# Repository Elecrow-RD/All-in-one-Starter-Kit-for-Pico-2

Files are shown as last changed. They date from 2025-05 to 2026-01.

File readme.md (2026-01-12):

### 1, Product picture

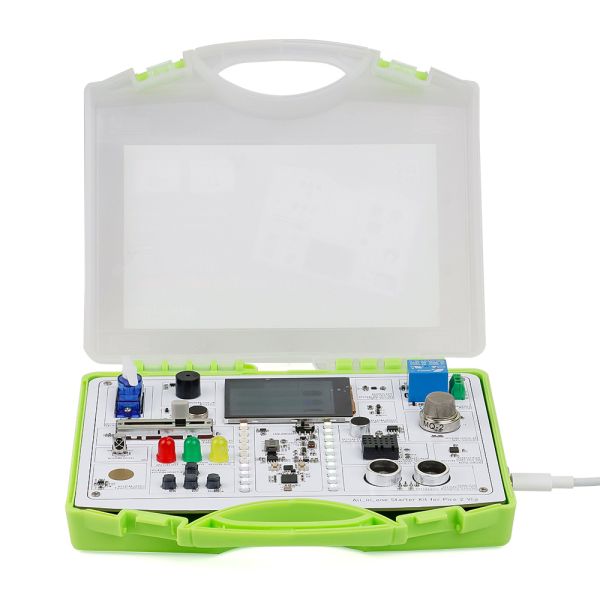
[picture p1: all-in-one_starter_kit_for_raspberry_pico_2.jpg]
all-in-one_starter_kit_for_raspberry_pico_2


https://www.elecrow.com/all-in-one-starter-kit-for-pico-2-with-common-board-design-17-sensors-and-21-lessons.html

### 2, Product version number

| | Hardware | Software | Remark |
| ---- | --- | --- | --- |
| 1 | V1.0 | V1.0 | old |
| 1 | V1.1 | V1.1 | old |
| 1 | V1.2 | V1.1 | old |
| 1 | V1.3 | V1.1 | latest |

#### v1.1 Update:

Replaced gyroscope sensor chip, removed MPU6050 circuit, and replaced it with LSM6DS3 circuit. Rearranged positions of red, green, and yellow LED beads.

#### v1.3 Update:
Added a switching power supply for the servo.

### 3, product information

- Main Processor IC: RP2350A
- Interface: Type-C Interface
- Size: 195*170*46(mm)
- Material:PP(Non-toxic)
- Weight: 340g

| | [ All-in-one Starter Kit for Pico 2](https://www.elecrow.com/all-in-one-starter-kit-for-pico-2-with-common-board-design-17-sensors-and-21-lessons.html) |
| --- | --- |
| Main Processor | Pico 2 RP2350 |
| Number of Sensors | 17 sensors |
| Sensor Board Design | Integrated sensor board, no soldering or complex wiring required |
| Screen | 2.4-inch TFT full-color touch screen |
| Ambient Lights | 20 full-color ambient lights, switchable via touch screen |
| Built-in Mini Games | Yes |
| Expansion Interfaces | None |
| Programming Environment | Based on Arduino software |
| Number of Tutorials | 21 creative tutorials |
| Dimension | 195×170×46 mm |
| Target Audience | Students, teachers, hardware enthusiasts |
| Application Scenarios | Ideal for learning Pico 2 programming basics |

### 4,Quick Start

##### Arduino IDE starts

1.Download the library files used by this product to the 'libraries' folder.

C:\Users\Documents\Arduino\libraries\



2.Open the Arduino IDE

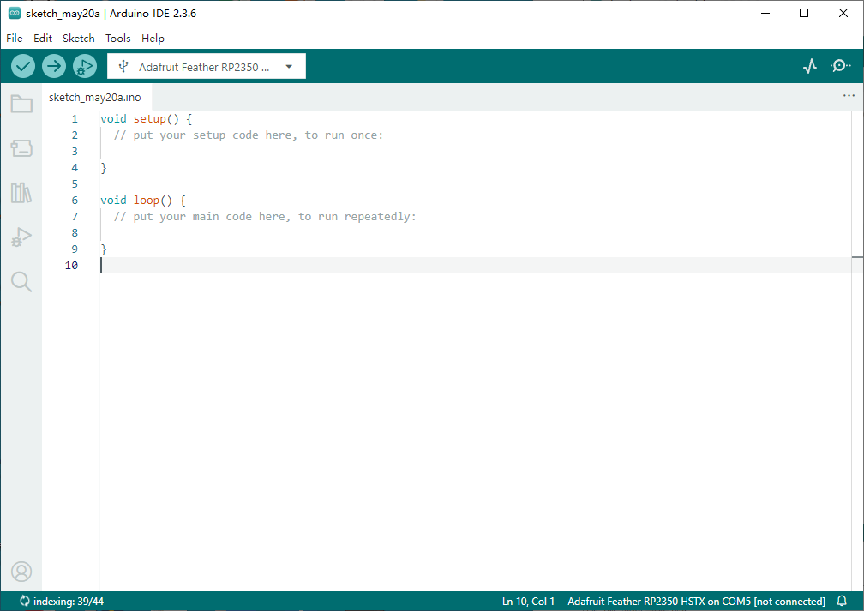
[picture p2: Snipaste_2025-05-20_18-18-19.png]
Snipaste_2025-05-20_18-18-19


3.Open the code configuration environment and burn it

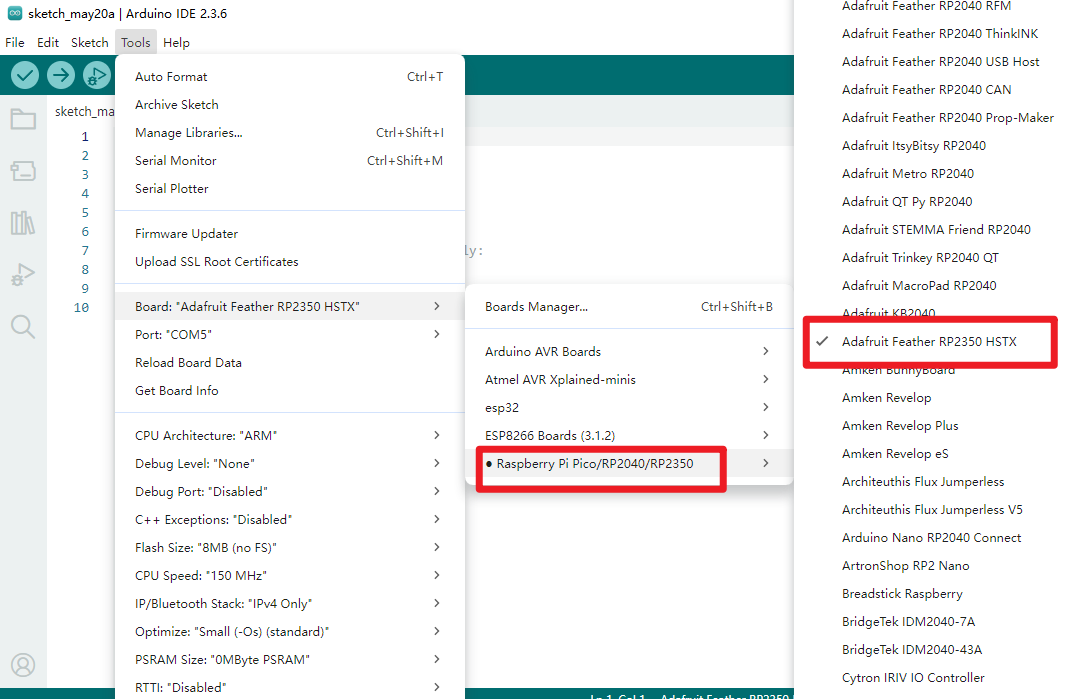
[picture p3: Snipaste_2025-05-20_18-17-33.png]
Snipaste_2025-05-20_18-17-33


### 5,Folder structure.

|--3D file： Contains 3D model files (.stp) for the hardware. These files can be used for visualization, enclosure design, or integration into CAD software.

|--Datasheet: Includes datasheets for components used in the project, providing detailed specifications, electrical characteristics, and pin configurations.

|--Eagle_SCH&PCB: Contains **Eagle CAD** schematic (`.sch`) and PCB layout (`.brd`) files. These are used for circuit design and PCB manufacturing.

|--example: Provides example code and projects to demonstrate how to use the hardware and libraries. These examples help users get started quickly.

|--factory_firmware: Stores pre-compiled factory firmware that can be directly flashed onto the device. This ensures the device runs the default functionality.

|--factory_sourcecode: Contains the source code for the factory firmware, allowing users to modify and rebuild the firmware as needed.

### 6,Pin definition

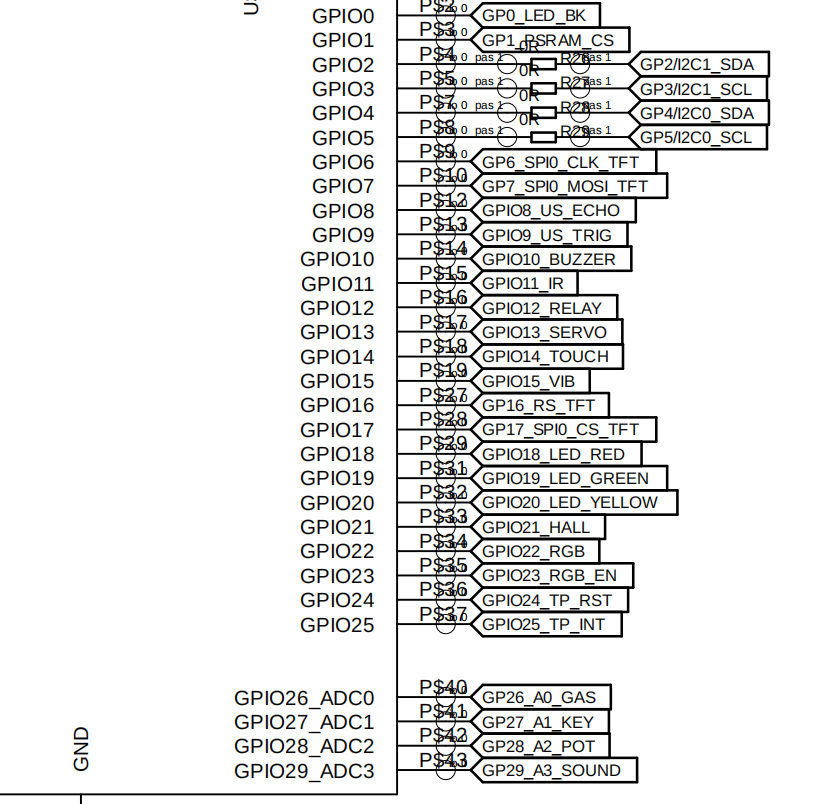
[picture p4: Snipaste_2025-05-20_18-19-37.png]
Snipaste_2025-05-20_18-19-37


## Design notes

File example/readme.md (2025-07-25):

**pico_Arduino_code**: This folder contains sample programs for the Arduino platform, known for its ease of use and versatility in creating interactive electronic projects.

For course code guidance, please refer to this manual：

[All-in-one_Starter_Kit_for_Pico_2_User_Manual](https://www.elecrow.com/download/product/SEP0005K/All-in-one_Starter_Kit_for_Pico_2_User_Manual.pdf)

**pico_micropython_code**: This folder contains sample programs and firmware for the micropython platform.

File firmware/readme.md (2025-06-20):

## Factory Firmware Download Guide

#### 1.Use type-c cable to connect the pico device, long press the boot button, then short press the reset button once, and finally release the boot button, you can see a new disc drive in my computer.



#### 2.Drag and drop the factory firmware xxx.uf2 file to the new disc drive and copy it to finish.





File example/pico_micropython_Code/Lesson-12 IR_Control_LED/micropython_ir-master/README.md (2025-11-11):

# Device drivers for IR (infra red) remote controls

This repo provides a driver to receive from IR (infra red) remote controls and
a driver for IR "blaster" apps. The device drivers are nonblocking. They do not
require `uasyncio` but are compatible with it, and are designed for standard
firmware builds.

The receiver is cross platform and has been tested on Pyboard, ESP8266, ESP32
and Raspberry Pi Pico.

In a typical use case the receiver is employed at the REPL to sniff the address
and data values associated with buttons on a remote control. The transmitter is
then used in an application to send those codes, emulating the remote control.

Other use cases involve running the receiver in an application. This enables an
IR remote to control a device such as a robot. This may be problematic on some
platforms. Please see [section 4](./README.md#4-receiver-limitations).

## Raspberry Pi Pico note

Early firmware has [this issue](https://github.com/micropython/micropython/issues/6866)
affecting USB communication with some PC's. This is now fixed. Please ensure
you are using up to date firmware.

#### [Receiver docs](./RECEIVER.md)

The transmitter driver is compatible with Pyboard (1.x and D series) and ESP32.
ESP8266 is unsupported; it seems incapable of generating the required signals.

#### [Transmitter docs](./TRANSMITTER.md)

# 1. IR communication

IR communication uses a carrier frequency to pulse the IR source. Modulation
takes the form of OOK (on-off keying). There are multiple protocols and at
least three options for carrier frequency: 36, 38 and 40KHz.

In the case of the transmitter the carrier frequency is a runtime parameter:
any value may be specified. The receiver uses a hardware demodulator which
should be purchased for the correct frequency. The receiver device driver sees
the demodulated signal and is hence carrier frequency agnostic.

Remotes transmit an address and a data byte, plus in some cases an extra value.
The address denotes the physical device being controlled. The data defines the
button on the remote. Provision usually exists for differentiating between a
button repeatedly pressed and one which is held down; the mechanism is protocol
dependent.

# 2. Supported protocols

The drivers support NEC and Sony protocols plus two Philips protocols, namely
RC-5 and RC-6 mode 0. There is also support for the OrtekMCE protocol used on
VRC-1100 remotes. These originally supported Microsoft Media Center but can be
used to control Kodi and (with a suitable receiver) to emulate a PC keyboard.
The Samsung protocol (NEC variant) is also supported.

Examining waveforms from various remote controls it is evident that numerous
protocols exist. Some are doubtless proprietary and undocumented. The supported
protocols are those for which I managed to locate documentation. My preference
is for the NEC version. It has conservative timing and good provision for error
detection. RC-5 has limited error detection, and RC-6 mode 0 has rather fast
timing.

A remote using the NEC protocol is [this one](https://www.adafruit.com/products/389).

# 3. Hardware Requirements

These are discussed in detail in the relevant docs; the following provides an
overview.

The receiver is cross-platform. It requires an IR receiver chip to demodulate
the carrier. The chip must be selected for the frequency in use by the remote.
For 38KHz devices a receiver chip such as the Vishay TSOP4838 or the
[adafruit one](https://www.adafruit.com/products/157) is required. This
demodulates the 38KHz IR pulses and passes the demodulated pulse train to the
microcontroller.

In my testing a 38KHz demodulator worked with 36KHz and 40KHz remotes, but this
is obviously neither guaranteed nor optimal.

The transmitter requires a Pyboard 1.x (not Lite), a Pyboard D, an ESP32 or
Raspberry Pico (RP2). Output is via an IR LED which will need a transistor to
provide sufficient current.

## 3.1 Carrier frequencies

These are as follows. The Panasonic remote appears to use a proprietary
protocol and is not supported by these drivers.

| Protocol  | F KHz | How found | Support |
|:---:|:-----:|:---:|:---:|
| NEC | 38 | Measured | Y |
| RC-5 RC-6 | 36 | Spec/measured | Y |
| Sony | 40 | Spec/measured | Y |
| MCE | 38 | Measured | Y | 
| Samsung | 38 | Measured | Y |
| Panasonic | 36.3  | Measured | N |

# 4. Receiver limitations

The receiver uses a pin interrupt and depends on a quick response to a state
change on the pin. This is guaranteed on platforms which support hard IRQ's
such as the Pyboard and the RP4 Pico. The ESP32 and ESP8266 only support soft
IRQ's. This means that, if code such as WiFi communication is running
concurrently, reliable reception may be problematic.

# 5. References

Sources of information about IR protocols. The `sbprojects.net` site is an
excellent resource.  
[General information about IR](https://www.sbprojects.net/knowledge/ir/)

Also [IRMP](https://www.mikrocontroller.net/articles/IRMP_-_english)

The NEC protocol:  
[altium](http://techdocs.altium.com/display/FPGA/NEC+Infrared+Transmission+Protocol)  
[circuitvalley](http://www.circuitvalley.com/2013/09/nec-protocol-ir-infrared-remote-control.html)  
[sbprojects.net](https://www.sbprojects.net/knowledge/ir/nec.php)

The Samsung protocol:  
[Rustic Engineering](https://rusticengineering.wordpress.com/2011/02/09/infrared-room-control-with-samsung-ir-protocol/)  
[TechDesign Electronics](https://www.techdesign.be/projects/011/011_waves.htm) Waveforms of various protocols.  

Philips protocols:  
[RC5 Wikipedia](https://en.wikipedia.org/wiki/RC-5)  
[RC5 sbprojects.net](https://www.sbprojects.net/knowledge/ir/rc5.php)  
[RC6 sbprojects.net](https://www.sbprojects.net/knowledge/ir/rc6.php)

Sony protocol:  
[SIRC sbprojects.net](https://www.sbprojects.net/knowledge/ir/sirc.php)

MCE protocol:  
[OrtekMCE](http://www.hifi-remote.com/johnsfine/DecodeIR.html#OrtekMCE)

IR decoders (C sourcecode):  
[in the Linux kernel](https://github.com/torvalds/linux/tree/master/drivers/media/rc)

Interesting summary of IR protools (with thanks to Martin Bless):  
[IRMP](https://www.mikrocontroller.net/articles/IRMP_-_english#IR_Protocols)

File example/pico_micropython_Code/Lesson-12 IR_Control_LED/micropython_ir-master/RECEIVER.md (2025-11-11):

# IR Receiver

##### [Main README](./README.md#1-ir-communication)

# 1. Hardware Requirements

The receiver is cross-platform. It requires an IR receiver chip to demodulate
the carrier. The chip must be selected for the frequency in use by the remote.
For 38KHz devices a receiver chip such as the Vishay TSOP4838 or the
[adafruit one](https://www.adafruit.com/products/157) is required. This
demodulates the 38KHz IR pulses and passes the demodulated pulse train to the
microcontroller. The tested chip returns a 0 level on carrier detect, but the
driver design ensures operation regardless of sense.

In my testing a 38KHz demodulator worked with 36KHz and 40KHz remotes, but this
is obviously neither guaranteed nor optimal.

The TSOP4838 can run from 3.3V or 5V supplies. The former should be used on
non-5V compliant hosts such as ESP32 and Raspberry Pi Pico and is fine on 5V
compliant hosts too.

The pin used to connect the decoder chip to the target is arbitrary. The test
program `acquire.py` uses the following pins by default:

| Host | Pin | Notes |
|:---:|:---:|:-----:|
| Pyboard | X3  |  |
| ESP32 | 23  |  |
| ESP8266 | 13  |  |
| D1 Mini | D7  | WeMos name for pin 13. |
| Pico | 16  |  |

A remote using the NEC protocol is [this one](https://www.adafruit.com/products/389).

# 2. Installation and demo scripts

The receiver is a Python package. This minimises RAM usage: applications only
import the device driver for the protocol in use. It may be installed using
 [mpremote](https://docs.micropython.org/en/latest/reference/mpremote.html) on
 the PC:
```bash
$ mpremote mip install "github:peterhinch/micropython_ir/ir_rx"
```
There are no dependencies.

## 2.1 Test scripts

The demo can be used to characterise IR remotes where the protocol is known. It
displays the codes returned by each button. This can aid in the design of
receiver applications. The demo prints "running" every 5 seconds and reports
any data received from the remote.
```python
from ir_rx.test import test
```
Instructions will be displayed at the REPL.

If the protocol in use is unknown, there are two options: trial and error with
the above script or run the following:
```python
from ir_rx.acquire import test
test()
```
This script waits for a single burst from the remote and prints the timing of
the pulses followed by its best guess at the protocol. It correctly identifies
supported protocols, but can wrongly identify unsupported protocols. The
report produced by the script exposed to an unknown protocol is unpredictable.
The `test()` function returns a list of the mark and space periods (in μs).

# 3. The driver

This implements a class for each supported protocol. Each class is subclassed
from a common abstract base class in `__init__.py`.

Applications should instantiate the appropriate class with a callback. The
callback will run whenever an IR pulse train is received. Example running on a
Pyboard:
```python
import time
from machine import Pin
from pyb import LED
from ir_rx.nec import NEC_8  # NEC remote, 8 bit addresses

red = LED(1)

def callback(data, addr, ctrl):
    if data < 0:  # NEC protocol sends repeat codes.
        print('Repeat code.')
    else:
        print('Data {:02x} Addr {:04x}'.format(data, addr))

ir = NEC_8(Pin('X3', Pin.IN), callback)
while True:
    time.sleep_ms(500)
    red.toggle()
```

#### Common to all classes

##### Constructor args:  
 1. `pin` is a `machine.Pin` instance configured as an input, connected to the
 IR decoder chip.  
 2. `callback` is the user supplied callback.
 3. `*args` Any further args will be passed to the callback.  

The user callback takes the following args:  
 1. `data` (`int`) Value from the remote. Normally in range 0-255. A value < 0
 signifies an NEC repeat code.
 2. `addr` (`int`) Address from the remote.
 3. `ctrl` (`int`) The meaning of this is protocol dependent:  
 NEC: 0  
 Philips: this is toggled 1/0 on repeat button presses. If the button is held
 down it is not toggled. The  transmitter demo implements this behaviour.  
 Sony: 0 unless receiving a 20-bit stream, in which case it holds the extended
 value.
 4. Any args passed to the constructor.

Bound variable:  
 1. `verbose=False` If `True` emits debug output.

##### Methods:
 1. `error_function` Arg: a function taking a single `int` arg. If specified
 the function will be called if an error occurs. The arg value corresponds to
 the error code. Typical usage might be to provide some user feedback of
 incorrect reception although beware of occasional triggers by external events.
 In my testing the TSOP4838 produces 200µs pulses on occasion for no obvious
 reason. See [section 4](./RECEIVER.md#4-errors).
 2. `close` No args. Shuts down the pin and timer interrupts.

A function is provided to print errors in human readable form. This may be
invoked as follows:

```python
from ir_rx.print_error import print_error  # Optional print of error codes
# Assume ir is an instance of an IR receiver class
ir.error_function(print_error)
```
##### Class variables:
 1. `Timer_id=-1` By default the driver uses a software timer. The ESP32C3  does
 not support these. This class variable offers a workround, See
 [section 5.1](./RECEIVER.md#51-timer-id).
 2. There are constants defining the NEC repeat code and the error codes sent
 to the error function. They are discussed in [section 4](./RECEIVER.md#4-errors).

Users of `uasyncio` please see [Section 8](./RECEIVER.md#8-use-with-uasyncio).

#### NEC classes (includes Samsung)

`NEC_8`, `NEC_16`, `SAMSUNG`

Typical invocation:
```python
from ir_rx.nec import NEC_8
```

Remotes using the NEC protocol can send 8 or 16 bit addresses. If the `NEC_16`
class receives an 8 bit address it will get a 16 bit value comprising the
address in bits 0-7 and its one's complement in bits 8-15.  
The `NEC_8` class enables error checking for remotes that return an 8 bit
address: the complement is checked and the address returned as an 8-bit value.
A 16-bit address will result in an error.

The `SAMSUNG` class returns 16 bit address and data values. The remote sample
tested did not issue repeat codes - if a button is held down it simply repeated
the original value. In common with other NEC classes the callback receives a
value of 0 in the `ctrl` arg.

Thanks are due to J.E.Tannenbaum for information about the Samsung protocol. See
https://github.com/peterhinch/micropython_ir/issues/21#issuecomment-1300421694 and
https://github.com/peterhinch/micropython_ir/issues/44 for some test results.

#### Sony classes

`SONY_12`, `SONY_15`, `SONY_20`

Typical invocation:
```python
from ir_rx.sony import SONY_15
```

The SIRC protocol comes in 3 variants: 12, 15 and 20 bits. `SONY_20` handles
bitstreams from all three types of remote. Choosing a class matching the remote
improves the timing reducing the likelihood of errors when handling repeats: in
20-bit mode SIRC timing when a button is held down is tight. A worst-case 20
bit block takes 39ms nominal, yet the repeat time is 45ms nominal.  
A single physical remote can issue more than one type of bitstream. The Sony
remote tested issued both 12 bit and 15 bit streams.

#### Philips classes

`RC5_IR`, `RC6_M0`

Typical invocation:
```python
from ir_rx.philips import RC5_IR
```

These support the RC-5 (including RC-5X) and RC-6 mode 0 protocols
respectively.

#### Microsoft MCE class

`MCE`

Typical invocation:
```python
from ir_rx.mce import MCE
```

I have been unable to locate a definitive specification: the protocol was
analysed by a mixture of googling and experiment. Behaviour may change if I
acquire new information. The protocol is known as OrtekMCE and the remote
control is sold on eBay as VRC-1100.

The remote was designed for Microsoft Media Center and is used to control Kodi
on boxes such as the Raspberry Pi. With a suitable PC driver it can emulate a
PC keyboard and mouse. The mouse emulation uses a different protocol: the class
does not currently support it. Pressing mouse buttons and pad will cause the
error function (if provided) to be called.

Args passed to the callback comprise 4 bit `addr`, 6 bit `data` and 2 bit `ctrl`
with the latter having the value 0 for the first message and 2 for the message
sent on key release. Intermediate messages (where the key is held down) have
value 1.

There is a 4-bit checksum which is used by default. The algorithm requires an
initial 'seed' value which my testing proved to be 4. However the only
[documentation](http://www.hifi-remote.com/johnsfine/DecodeIR.html#OrtekMCE) I
could find stated that the value should be 3. I implemented this as a class
variable `MCE.init_cs=4`. This enables it to be changed if some remotes use 3.
If the value is set to -1 the check will be skipped.

# 4. Errors

IR reception is inevitably subject to errors, notably if the remote is operated
near the limit of its range, if it is not pointed at the receiver or if its
batteries are low. The user callback is not called when an error occurs.

On ESP8266 and ESP32 there is a further source of errors. This results from the
large and variable interrupt latency of the device which can exceed the pulse
duration. This causes pulses to be missed or their timing measured incorrectly.
On ESP8266 some improvment may be achieved by running the chip at 160MHz.

In general applications should provide user feedback of correct reception.
Users tend to press the key again if the expected action is absent.

In debugging a callback can be specified for reporting errors. The value passed
to the error function are represented by constants indicating the cause of the
error. These are driver ABC class variables and are as follows:

`BADSTART` A short (<= 4ms) start pulse was received. May occur due to IR
interference, e.g. from fluorescent lights. The TSOP4838 is prone to producing
200µs pulses on occasion, especially when using the ESP8266.  
`BADBLOCK` A normal data block: too few edges received. Occurs on the ESP8266
owing to high interrupt latency.  
`BADREP` A repeat block: an incorrect number of edges were received.  
`OVERRUN` A normal data block: too many edges received.  
`BADDATA` Data did not match check byte.  
`BADADDR` (`NEC_IR`) If `extended` is `False` the 8-bit address is checked
against the check byte. This code is returned on failure.  

# 5. Receiver platforms

Currently the ESP8266 suffers from [this issue](https://github.com/micropython/micropython/issues/5714).
Testing was therefore done without WiFi connectivity. If the application uses
the WiFi regularly, or if an external process pings the board repeatedly, the
crash does not occur.

Philips protocols (especially RC-6) have tight timing constraints with short
pulses whose length must be determined with reasonable accuracy. The Sony 20
bit protocol also has a timing issue in that the worst case bit pattern takes
39ms nominal, yet the repeat time is 45ms nominal. These issues can lead to
errors particularly on slower targets. As discussed above, errors are to be
expected. It is up to the user to decide if the error rate is acceptable.

Reception was tested using Pyboard D SF2W, ESP8266 and ESP32 with signals from
remote controls (where available) and from the tranmitter in this repo. Issues
are listed below.

NEC: No issues.  
Sony 12 and 15 bit: No issues.  
Sony 20 bit: On ESP32 some errors occurred when repeats occurred.  
Philips RC-5: On ESP32 with one remote control many errors occurred, but paired
with the transmitter in this repo it worked.  
Philips RC-6: No issues. Only tested against the transmitter in this repo.

## 5.1 Timer ID

The ESP32C3 does not support software timers. This results in a crash. It is
possible to assign a hardware timer as follows (example is for NEC but applies
to any class):
```python
from ir_rx.nec import NEC_8
NEC_8.Timer_id = 0  # Use hardware timer 0
# Code omitted
ir = NEC_8(Pin(8, Pin.IN), callback)
```
Note that assigning a hardware timer is only possible on platforms where the
timer callback is a soft interrupt service routine (see below).

Thanks are due to @Pax-IT for diagnosing this problem.

# 6. Principle of operation

Protocol classes inherit from the abstract base class `IR_RX`. This uses a pin
interrupt to store in an array the time (in μs) of each transition of the pulse
train from the receiver chip. Arrival of the first edge starts a software timer
which runs for the expected duration of an IR block (`tblock`). The use of a
software timer ensures that `.decode` and the user callback can allocate.

When the timer times out its callback (`.decode`) decodes the data. `.decode`
is a method of the protocol specific subclass; on completion it calls the
`do_callback` method of the ABC. This resets the edge reception and calls
either the user callback or the error function (if provided).

The size of the array and the duration of the timer are protocol dependent and
are set by the subclasses. The `.decode` method is provided in the subclass.

CPU times used by `.decode` (not including the user callback) were measured on
a Pyboard D SF2W at stock frequency. They were: NEC 1ms for normal data, 100μs
for a repeat code. Philips codes: RC-5 900μs, RC-6 mode 0 5.5ms.

# 7. Unsupported protocols

It is possible to capture an IR burst from a remote and to re-create it using
the transmitter. This has limitations and is discussed in detail in
[the transmitter doc](./TRANSMITTER.md#5-unsupported-protocols).

# 8. Use with uasyncio

The receiver callback runs in a soft ISR (interrupt service routine) context.
In normal synchronous code this is unlikely to present problems, but the fact
that an interrupt can occur at any time means that care must be taken to avoid
a risk of disrupting `uasyncio` internal data. "Thread safe" techniques should
be used. In particular it is bad practice to create a task in the callback. A
simple approach is to use a [ThreadSafeQueue](https://github.com/peterhinch/micropython-async/blob/master/v3/docs/THREADING.md#22-threadsafequeue):

```python
import uasyncio as asyncio
from threadsafe import ThreadSafeQueue
from machine import Pin
from ir_rx.nec import NEC_16

def callback(data, addr, ctrl, qu):  # Runs in ISR context
    if not qu.full():
        qu.put_sync((data, addr))

async def receiver(q):
    async for data in q:  # Task pauses here until data arrives
        print(f"Received {data}")

async def main():
    q = ThreadSafeQueue([0 for _ in range(20)])
    ir = NEC_16(Pin(16, Pin.IN), callback, q)
    await receiver(q)

asyncio.run(main())
```

The underlying issues are discussed [here](https://github.com/peterhinch/micropython-async/blob/master/v3/docs/INTERRUPTS.md)
and [here](https://github.com/peterhinch/micropython-async/blob/master/v3/docs/THREADING.md).

# Appendix 1 NEC Protocol description

A normal burst comprises exactly 68 edges, the exception being a repeat code
which has 4. An incorrect number of edges is treated as an error. All bursts
begin with a 9ms pulse. In a normal code this is followed by a 4.5ms space; a
repeat code is identified by a 2.25ms space. A data burst lasts for 67.5ms.

Data bits comprise a 562.5µs mark followed by a space whose length determines
the bit value. 562.5µs denotes 0 and 1.6875ms denotes 1.

In 8 bit address mode the complement of the address and data values is sent to
provide error checking. This also ensures that the number of 1's and 0's in a
burst is constant, giving a constant burst length of 67.5ms. In extended
address mode this constancy is lost. The burst length can (by my calculations)
run to 76.5ms.

# Appendix 2 MCE Protocol

The bitstream comprises a header (2ms mark, 1ms space) followed by 16 bits of
Manchester encoded data with a bit time of 500μs. Data are encoded  
```
ccccddddddppaaaa
```
Where `aaaa` is the address, `pp` is the position (toggle) field, `dddddd` is
data and `cccc` is a checksum. This is calculated by counting the ones in
`ddddddppaaaa` and adding 4. Data are transmitted LSB first.

The only [doc](http://www.hifi-remote.com/johnsfine/DecodeIR.html#OrtekMCE) I
could find states that the checksum seed value is 3, but this did not match the
remote I have.

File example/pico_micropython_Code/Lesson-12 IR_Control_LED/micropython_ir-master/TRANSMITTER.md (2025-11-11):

# IR Transmitter

##### [Main README](./README.md#1-ir-communication)

# 1. Hardware Requirements

The transmitter requires a Pyboard 1.x (not Lite), a Pyboard D or an ESP32.
Output is via an IR LED which needs a simple circuit to provide sufficient
current. Typically these need 50-100mA of drive to achieve reasonable range and
data integrity. A suitable 940nm LED is [this one](https://www.adafruit.com/product/387).

On the Pyboard the transmitter test script assumes pin X1 for IR output. It can
be changed, but it must support Timer 2 channel 1. Pins for pushbutton inputs
are arbitrary: X3 and X4 are used. The driver uses timers 2 and 5.

On ESP32 the demo uses pin 23 for IR output and pins 18 and 19 for pushbuttons.
These pins may be changed. The only device resource used is `RMT(0)`.

On Raspberry Pi Pico the demo uses pin 17 for IR output and pins 18 and 19 for
pushbuttons. These pins may be changed. The driver uses the PIO to emulate a
device similar to the ESP32 RMT. The device driver is
[documented here](./RP2_RMT.md); this is for experimenters and those wanting to
use the library in conjunction with their own PIO assembler code.

## 1.1 Wiring

All microcontrollers require an external circuit to drive the LED. The notes
below on specific microcontrollers assume that such a circuit is used.

I use the following circuit which delivers just under 40mA to the diode. R2 may
be reduced for higher current.  
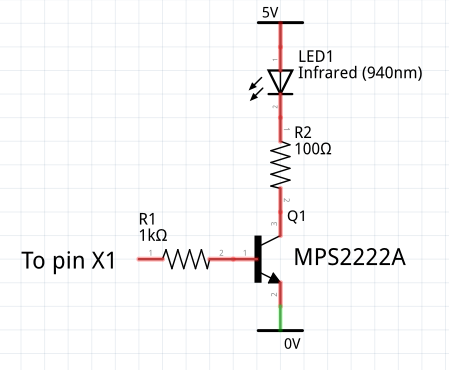
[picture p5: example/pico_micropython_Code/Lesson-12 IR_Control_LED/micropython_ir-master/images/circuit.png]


This alternative delivers a constant current of about 53mA if a higher voltage
than 5V is available. R4 determines the current value and may be reduced to
increase power.  
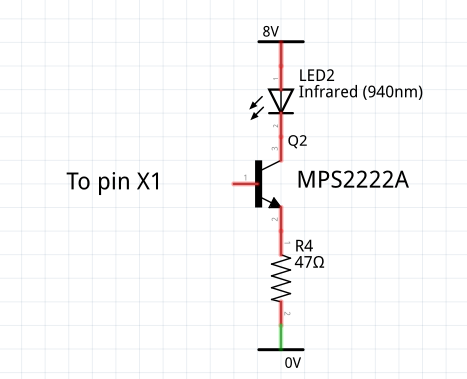
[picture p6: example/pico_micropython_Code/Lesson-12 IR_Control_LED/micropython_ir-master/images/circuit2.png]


The transistor type is not critical.

The driver assumes circuits as shown. Here the carrier "off" state is 0V,
which is the driver default. If using an alternative circuit where "off" is
required to be 3.3V, the class variable `active_high` should be set `False`.

## 1.2 ESP32 Wiring

The ESP32 RMT device now supports the carrier option, and this driver has been
updated to use it. The same circuits as above may be used to connect to pin 23
(or other pin, if the code has been adapted). The `active_high` option is not
available on the ESP32 `RMT` object, so any alternative circuit must illuminate
the LED if the pin state is high.

## 1.3 RP2 Wiring

There is no `active_high` option so the circuit  must illuminate the LED if the
pin state is high, as per the above drivers. Test programs use pin 17, but this
can be reassigned.

# 2. Dependencies and installation

## 2.1 Dependencies

The device driver has no dependencies.

On ESP32 a firmware version >= V1.17 is required.

The demo program uses `uasyncio` primitives from
[this repo](https://github.com/peterhinch/micropython-async). These may be
installed with
```bash
$ mpremote mip install "github:peterhinch/micropython-async/v3/primitives"
```

## 2.2 Installation

The transmitter is a Python package. This minimises RAM usage: applications
only import the device driver for the protocol in use. It may be installed using
 [mpremote](https://docs.micropython.org/en/latest/reference/mpremote.html) on
 the PC:
```bash
$ mpremote mip install "github:peterhinch/micropython_ir/ir_tx"
```
The demo is of a 2-button remote controller with auto-repeat. It may be run by
issuing:
```python
from ir_tx.test import test
```
Instructions will be displayed at the REPL.

# 3. The driver

This is specific to Pyboard D, Pyboard 1.x (not Lite), ESP32 and Raspberry Pi
Pico (RP2 architecture chip).

It implements a class for each supported protocol, namely `NEC`, `SONY_12`,
`SONY_15`, `SONY_20`, `RC5` and `RC6_M0`.  Each class is subclassed from a
common abstract base class in `__init__.py`. The application instantiates the
appropriate class and calls the `transmit` method to send data.

Basic usage on a Pyboard:
```python
from machine import Pin
from ir_tx.nec import NEC
nec = NEC(Pin('X1'))
nec.transmit(1, 2)  # address == 1, data == 2
```
Basic usage on ESP32:
```python
from machine import Pin
from ir_tx.nec import NEC
nec = NEC(Pin(23, Pin.OUT, value = 0))
nec.transmit(1, 2)  # address == 1, data == 2
```
Basic usage on Pico:
```python
from machine import Pin
from ir_tx.nec import NEC
nec = NEC(Pin(17, Pin.OUT, value = 0))
nec.transmit(1, 2)  # address == 1, data == 2
```

#### Common to all classes

Constructor args:  
 1. `pin` A Pin instance instantiated as an output. On a Pyboard this is a
 `pyb.Pin` instance supporting Timer 2 channel 1: `X1` is employed by the test
 script. On ESP32 any `machine.Pin` may be used. Must be connected to the IR
 diode as described below.
 2. `freq=default` The carrier frequency in Hz. The default for NEC is 38000,
 Sony is 40000 and Philips is 36000.
 3. `verbose=False` If `True` emits (a lot of) debug output.

Methods:
 1. `transmit(addr, data, toggle=0, validate=False)` Args `addr`, `data` and
 `toggle` are positive integers. The maximum vaues are protocol dependent. If
 `validate` is `True` passed values are checked and a `ValueError` raised if
 they are out of range. If `validate` is false invalid bits are silently
 discarded. For example if an address of 0x11 is passed to `MCE.transmit`, the
 address sent will be 1 because that protocol supports only a four bit address
 field. The `toggle` field is unused by some protocols when 0 should be passed.
 2. `busy()` Returns `True` while data is being transmitted.

Class method:
 1. `active_low` No args. Pyboard only. A `ValueError` will be thrown on ESP32.
 The IR LED drive circuit is usually designed to turn the LED on if the driver
 pin is high. If it has opposite polarity the method must be called before
 instantiating the class - it will be ineffective if called later.

Class varaible:
 1. `timeit=False` If `True` the `.transmit` method times itself and prints the
 result in μs.

The `transmit` method is synchronous with rapid return. Actual transmission
occurs as a background process, on the Pyboard controlled by timers 2 and 5. On
ESP32 the RMT class is used and on RP2 the PIO is used to emulate the RMT. If
`transmit` is called while a prior transmission is in progress, it will block
until the transmission is complete before commencing the next. Blocking can be
avoided by checking the `busy` status prior to starting a transmission. Note
that sending bursts in quick succession may confuse the receiving device: these
are typically designed for a transmitter that sends a burst in response to a
button press with a gap likely to be well over 100ms.

Execution times were measured on a Pyboard 1.1 and the ESP32 reference board
without SPIRAM. Tests were done at stock frequency and with `validate=True`,
`verbose=False`. A small saving could be achieved by skipping validation.

| Protocol | ESP32 | Pyboard |
|:---:|:-----:|:---:|
| NEC | 7.8ms | 3.2ms |
| SONY12 | 3.2ms | 1.3ms |
| SONY15 | 3.6ms | 1.5ms |
| SONY20 | 4.5ms | 1.9ms |
| RC5 | 4.9ms | 1.5ms |
| RC6_M0 | 6.0ms | 2.0ms |
| MCE | 6.7ms | 2.0ms |

#### NEC class (also Samsung)

Class `NEC`. Example invocation:
```python
from ir_tx.nec import NEC
```

This has an additional method `.repeat` (no args). This causes a repeat code to
be transmitted. Should be called every 108ms if a button is held down.

The NEC protocol accepts 8 or 16 bit addresses. In the former case, a 16 bit
value is transmitted comprising the 8 bit address and its one's complement,
enabling the receiver to perform a simple error check. The `NEC` class supports
these modes by checking the value of `addr` passed to `.transmit` and sending
the complement for values < 256.

A value passed in `toggle` is ignored.

For Samsung protocol set the `samsung` class variable `True`:
```python
from ir_tx.nec import NEC
NEC.samsung=True
```
Samsung remotes do not seem to use repeat codes: the sample I have simply
repeats the original code.

Thanks are due to J.E.Tannenbaum for information about the Samsung protocol. See
https://github.com/peterhinch/micropython_ir/issues/21#issuecomment-1300421694 and
https://github.com/peterhinch/micropython_ir/issues/44 for some test results.

#### Sony classes

Classes `SONY_12`, `SONY_15` and `SONY_20`. Example invocation:
```python
from ir_tx.sony import SONY_15
```

The SIRC protocol supports three sizes, supported by the following classes:
 1. 12 bit (7 data, 5 address) `SONY_12`
 2. 15 bit (7 data, 8 address) `SONY_15`
 3. 20 bit (7 data, 5 addresss, 8 extended) `SONY_20`

The `.transmit` method masks `addr` and `data` values to the widths listed
above. `toggle` is ignored except by `SONY_20` which treats it as the extended
value.

#### Philips classes

Classes `RC5` and `RC6_M0`. Example invocation:
```python
from ir_tx.philips import RC5
```

The RC-5 protocol supports a 5 bit address and 6 or 7 bit (RC5X) data. The
driver uses the appropriate mode depending on the `data` value provided.

The RC-6 protocol accepts 8 bit address and data values.

Both send a `toggle` bit which remains constant if a button is held down, but
changes when the button is released. The application should implement this
behaviour, setting the `toggle` arg of `.transmit` to 0 or 1 as required.

#### Microsoft MCE class

Class `MCE`. Example invocation:
```python
from ir_tx.mce import MCE
# MCE.init_cs = 3
```
There is a separate demo for the `MCE` class because of the need to send a
message on key release. It is run by issuing:
```python
from ir_tx.mcetest import test
```
Instructions will be displayed at the REPL.

I have been unable to locate a definitive specification: the protocol was
analysed by a mixture of googling and experiment. Behaviour may change if I
acquire new information. The protocol is known as OrtekMCE and the remote
control is sold on eBay as VRC-1100.

The remote was designed for Microsoft Media Center and is used to control Kodi
on boxes such as the Raspberry Pi. With a suitable PC driver it can emulate a
PC keyboard and mouse. The mouse emulation uses a different protocol: the class
does not currently support it. Pressing mouse buttons and pad will cause the
error function (if provided) to be called.

This supports a 4 bit address, 6 bit data and 2 bit toggle. The latter should
have a value of 0 for the first message, 1 for repeat messages, and 2 for a
final message sent on button release.

The remaining four bits are a checksum which the driver creates. The algorithm
requires an initial 'seed' value which my testing proved to be 4. However the
only [documentation](http://www.hifi-remote.com/johnsfine/DecodeIR.html#OrtekMCE)
I could find stated that the value should be 3. I implemented this as a class
variable `MCE.init_cs=4`. This enables it to be changed if some receivers
require 3.

# 4. Principle of operation

The classes inherit from the abstract base class `IR`. This has an array `.arr`
to contain the duration (in μs) of each carrier on or off period. The
`transmit` method calls a `tx` method of the subclass which populates this
array. This is done by two methods of the base class, `.append` and `.add`. The
former takes a list of times (in ) and appends them to the array. A bound
variable `.carrier` keeps track of the notional on/off state of the carrier:
this is required for bi-phase (manchester) codings.

The `.add` method takes a single μs time value and adds it to the last value
in the array: this pulse lengthening is used in bi-phase encodings.

On completion of the subclass `.tx`, `.transmit` calls `.trigger` which
initiates transmission as a background process. Its behaviour is platform
dependent.

## 4.1 Pyboard

Tramsmission is performed by two hardware timers initiated in the constructor.
Timer 2, channel 1 is used to configure the output pin as a PWM channel. Its
frequency is set in the constructor. The OOK is performed by dynamically
changing the duty ratio using the timer channel's `pulse_width_percent` method:
this varies the pulse width from 0 to the duty ratio passed to the constructor.

The duty ratio is changed by the Timer 5 callback `._cb`. This retrieves the
next duration from the array. If it is not `STOP` it toggles the duty cycle
and re-initialises T5 for the new duration. If it is `STOP` it ensures that the
duty ratio is set to the `_SPACE`

Here `.trigger` appends a special `STOP` value and initiates physical
transmission by calling the Timer5 callback.

## 4.2 ESP32

The RMT class now supports `carrier_freq` and `carrier_duty_percent`
constructor args, so the base class `IR` (in `__init__.py`) uses these to
enable the OOK (on-off keying) waveform.

The `.trigger` method calls `RMT.write_pulses` and returns with `RMT` operating
in the background.

## 4.3 Duty ratio

In every case where I could find a specified figure it was 30%. I measured
that from a variety of remotes, and in every case it was close to that figure.

# 5. Unsupported protocols

You can use the receiver module to capture an IR burst and replay it with the
transmitter. This enables limited support for unknown protocols. This is
strictly for experimenters and I haven't documented it in detail.

There are two limitations. The first is timing accuracy: both receiving and
transmitting processes introduce some timing uncertainty. This is only likely
to be a practical problem with fast protocols. In brief testing with a known
protocol the scripts below worked.

The more tricky problem is handling repeat keys: different protocols use widely
varying approaches. If repeat keys are to be supported some experimentation and
coding is likely to be required.

The following captures a single burst and saves it to a file:  
```python
from ir_rx.acquire import test
import ujson

lst = test()  # May report unsupported or unknown protocol
with open('burst.py', 'w') as f:
    ujson.dump(lst, f)
```
This replays it:  
```python
from ir_tx import Player
from sys import platform
import ujson

if platform == 'esp32':
    from machine import Pin
    pin = Pin(23, Pin.OUT, value = 0)
else:
    from pyb import Pin, LED
    pin = Pin('X1')
with open('burst.py', 'r') as f:
    lst = ujson.load(f)
ir = Player(pin)
ir.play(lst)
```
The `ir_tx.Player` class is a minimal subclass supporting only the `.play`
method. This takes as an arg an iterable comprising time values of successive
mark and space periods (in μs).

The `ir_rx.acquire.test` function makes assumptions about the likely maximum
length and maximum duration of a burst. In some cases this may require some
modification e.g. to instantiate `IR_GET` with different args.

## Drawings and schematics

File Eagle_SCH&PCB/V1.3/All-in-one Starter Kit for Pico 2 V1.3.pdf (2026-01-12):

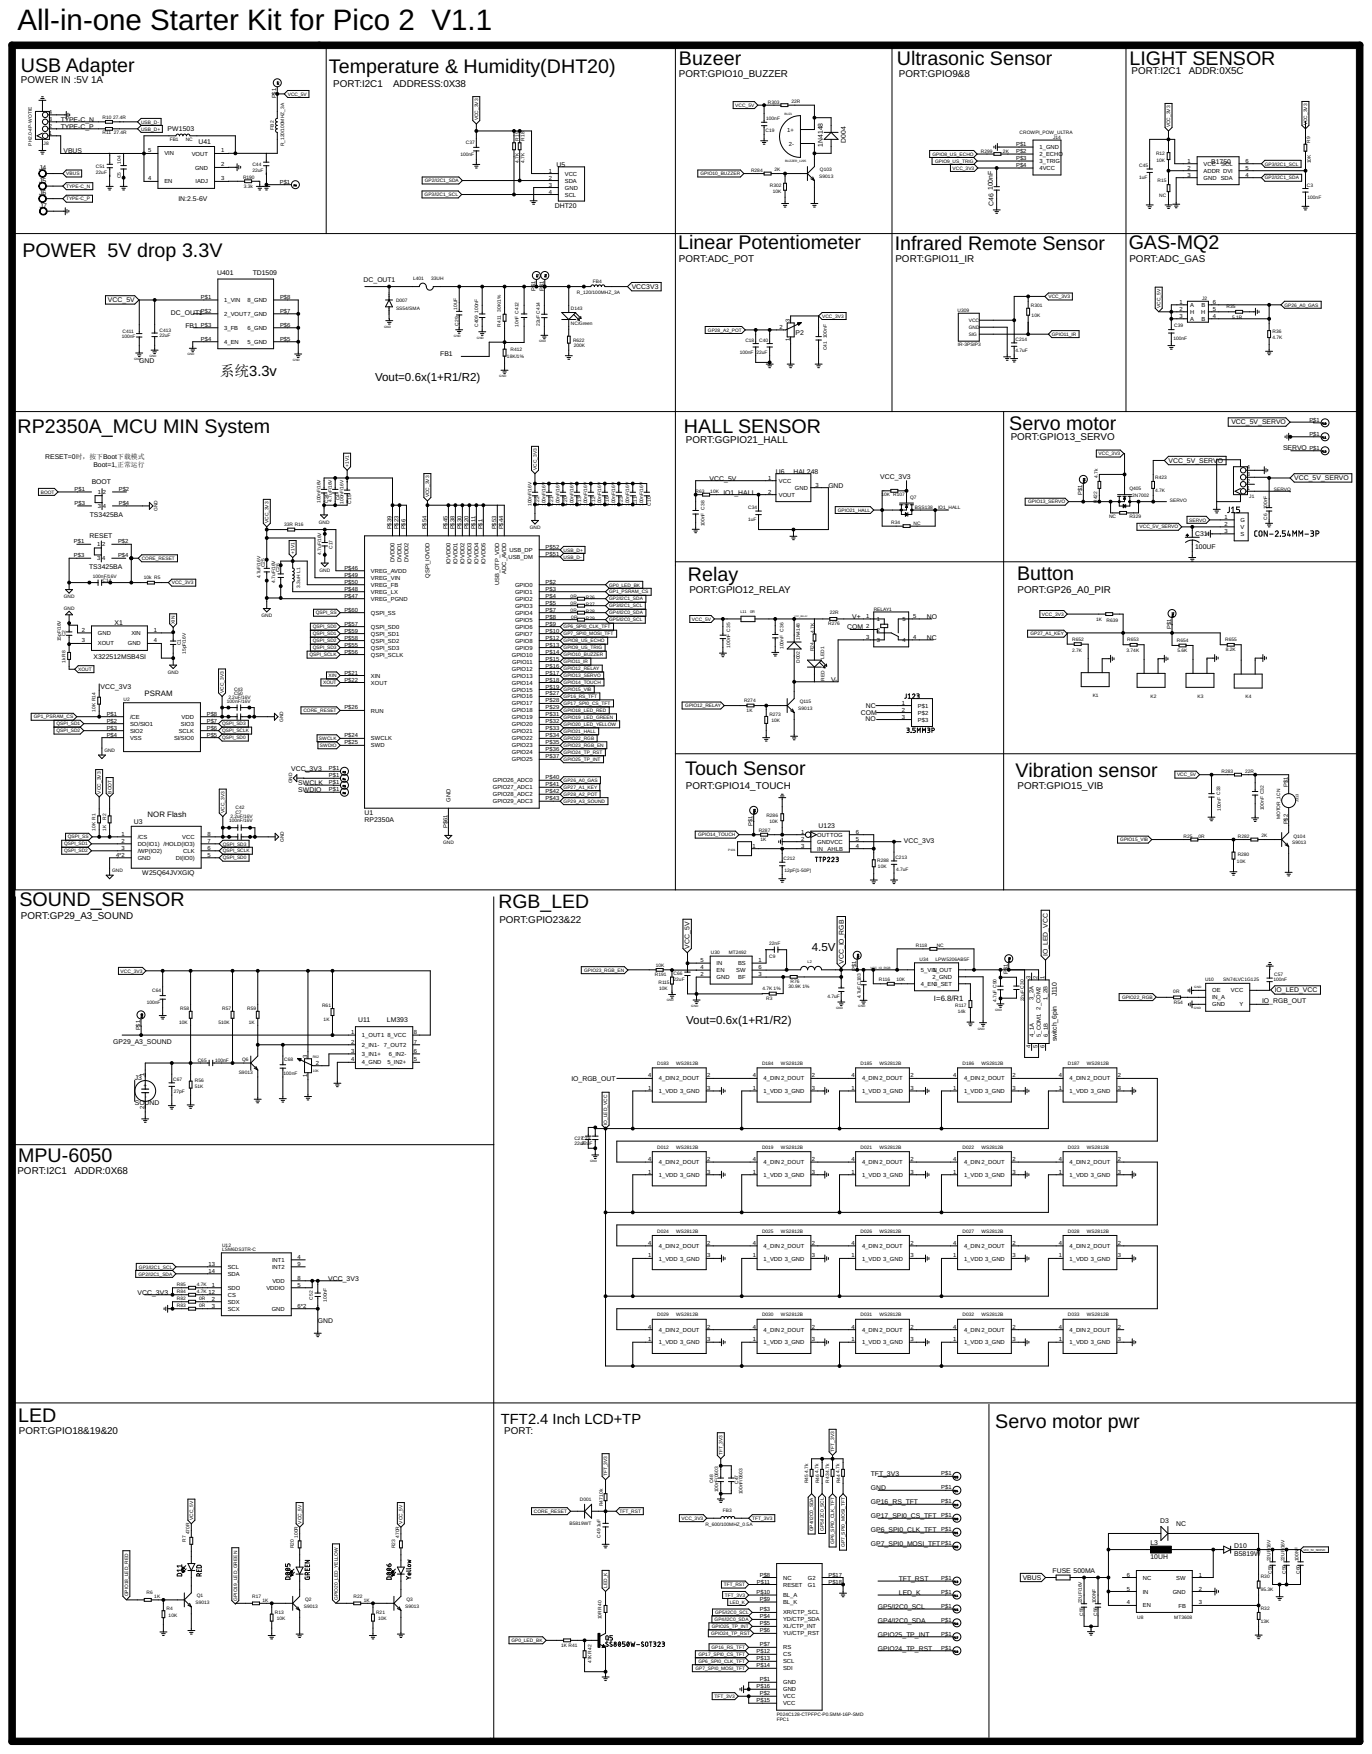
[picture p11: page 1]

All-in-one Starter Kit for Pico 2 V1.1

Infrared Remote Sensor PORT:GPIO11_IR

HALL SENSOR PORT:GGPIO21_HALL HAL248 | Servo motor PORT:GPIO13_SERVO P$1 P$1 P$1 VCC_5V_SERVO

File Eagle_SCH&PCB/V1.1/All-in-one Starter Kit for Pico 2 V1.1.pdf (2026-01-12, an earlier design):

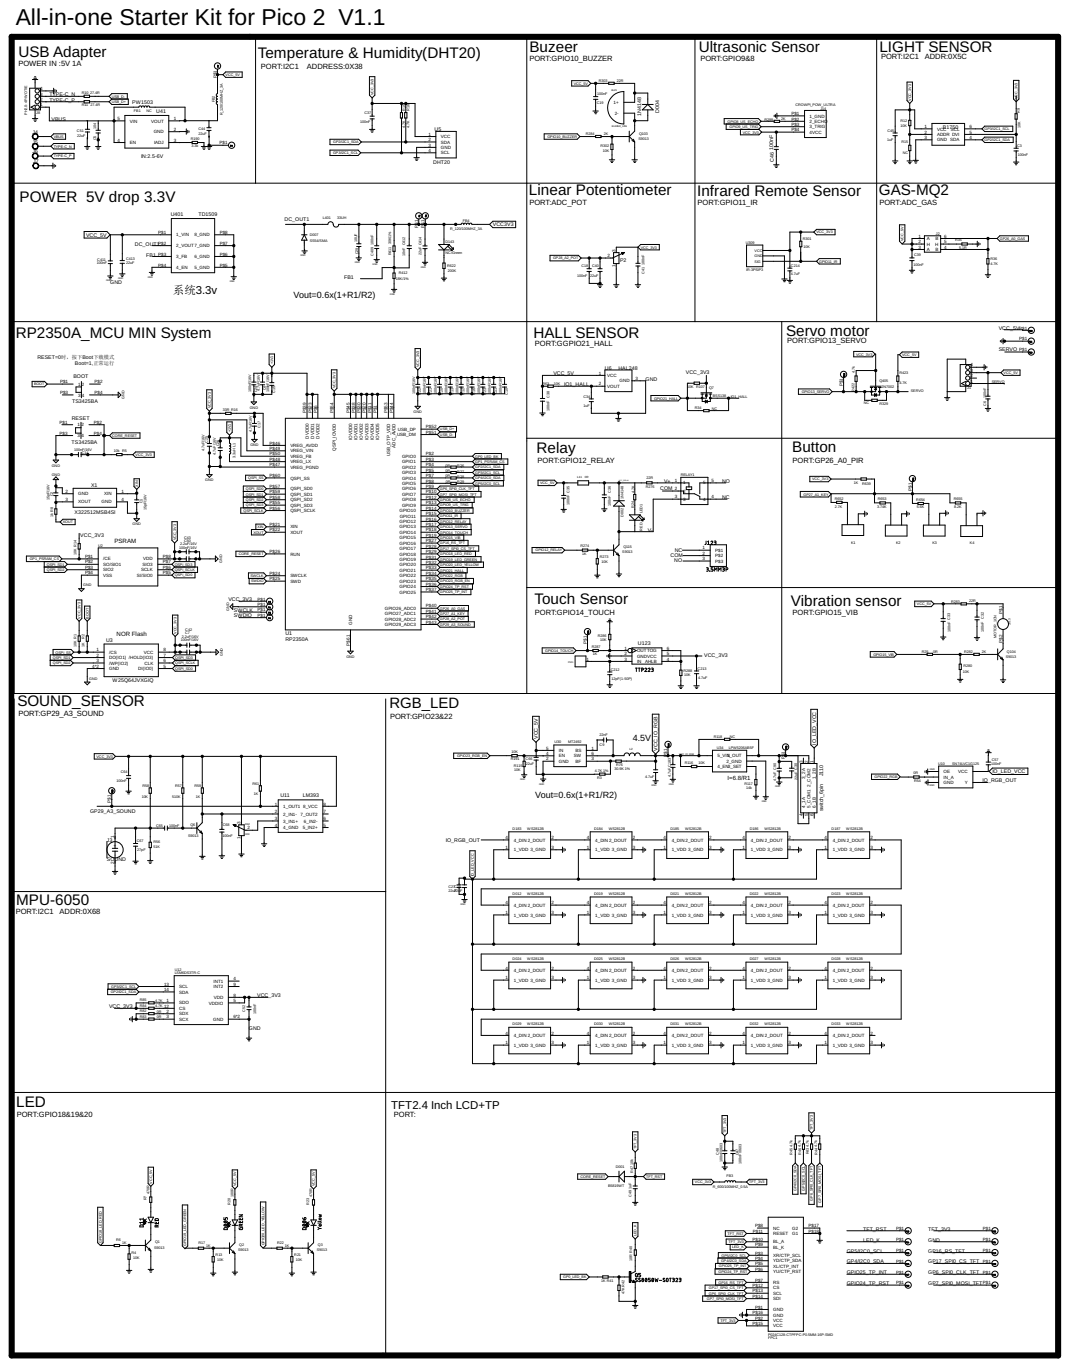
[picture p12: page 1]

All-in-one Starter Kit for Pico 2 V1.1

RP2350A_MCU MIN System | HALL SENSOR PORT:GGPIO21_HALL HAL248 | Servo motor VCC_5V PORT:GPIO13_SERVO

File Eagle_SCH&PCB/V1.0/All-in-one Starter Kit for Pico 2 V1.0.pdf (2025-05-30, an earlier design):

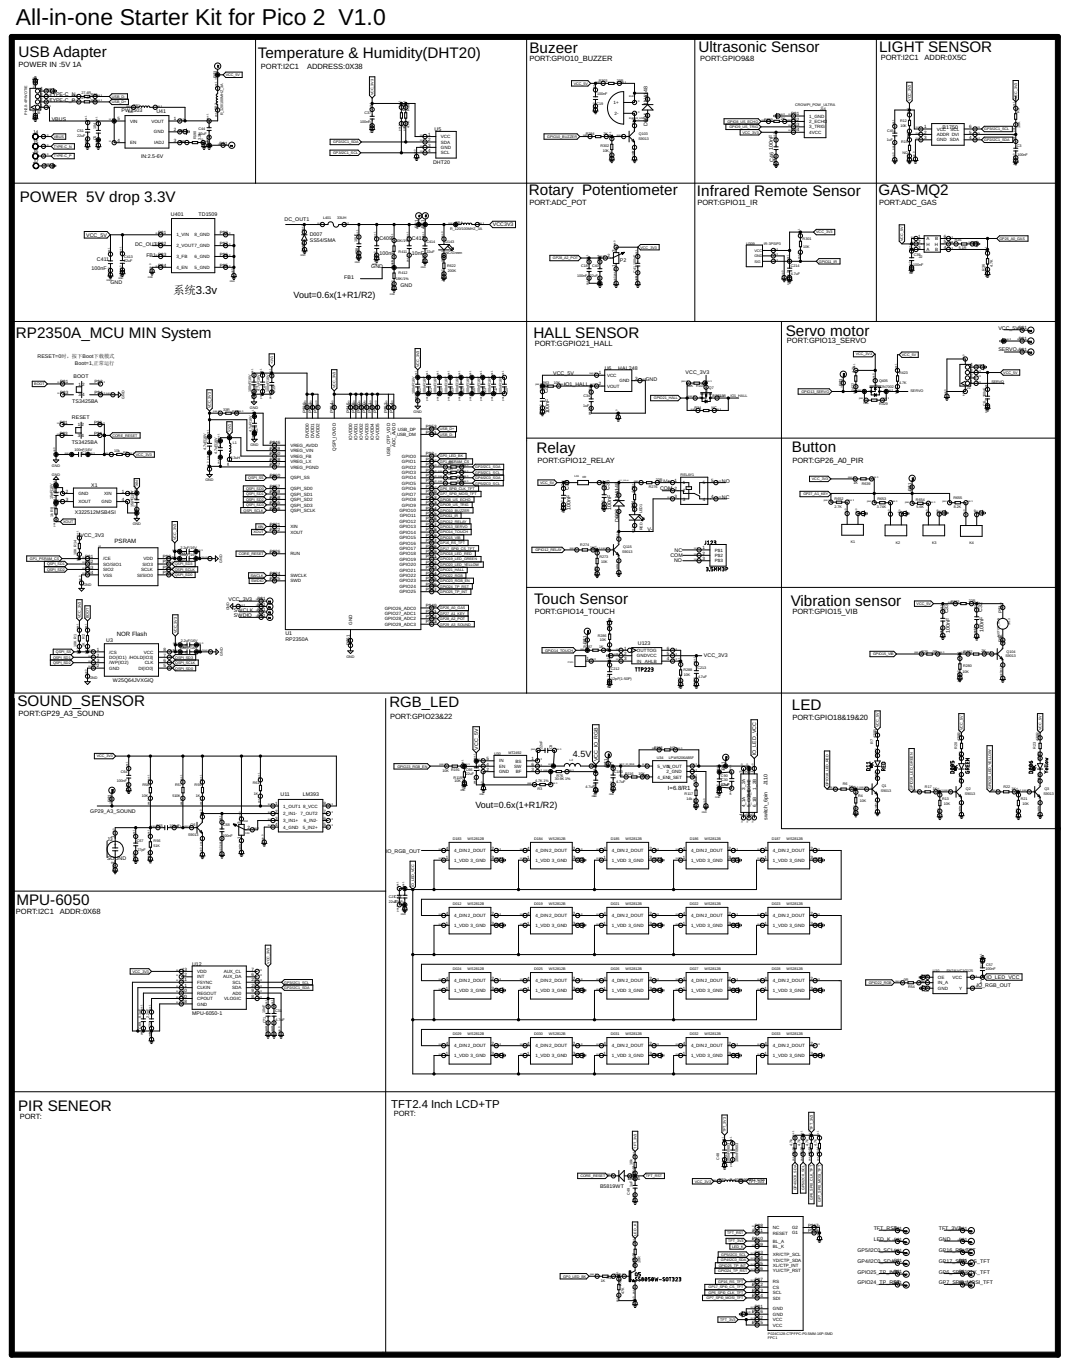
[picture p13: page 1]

All-in-one Starter Kit for Pico 2 V1.0

pas 1 pas 1

sup 0 pas 1 pas 1 pas 1 pas 1

pas 0 pas 0 pas 1 pas 1

pas 1 pas 1 pas 0 pas 0

MPU-6050 PORT:I2C1 ADDR:0X68

PIR SENEOR PORT: | TFT2.4 Inch LCD+TP

pas 3 pas 2 pas 1 pas 1

pas 1 pas 1 sup 0 pas 1 pas 1

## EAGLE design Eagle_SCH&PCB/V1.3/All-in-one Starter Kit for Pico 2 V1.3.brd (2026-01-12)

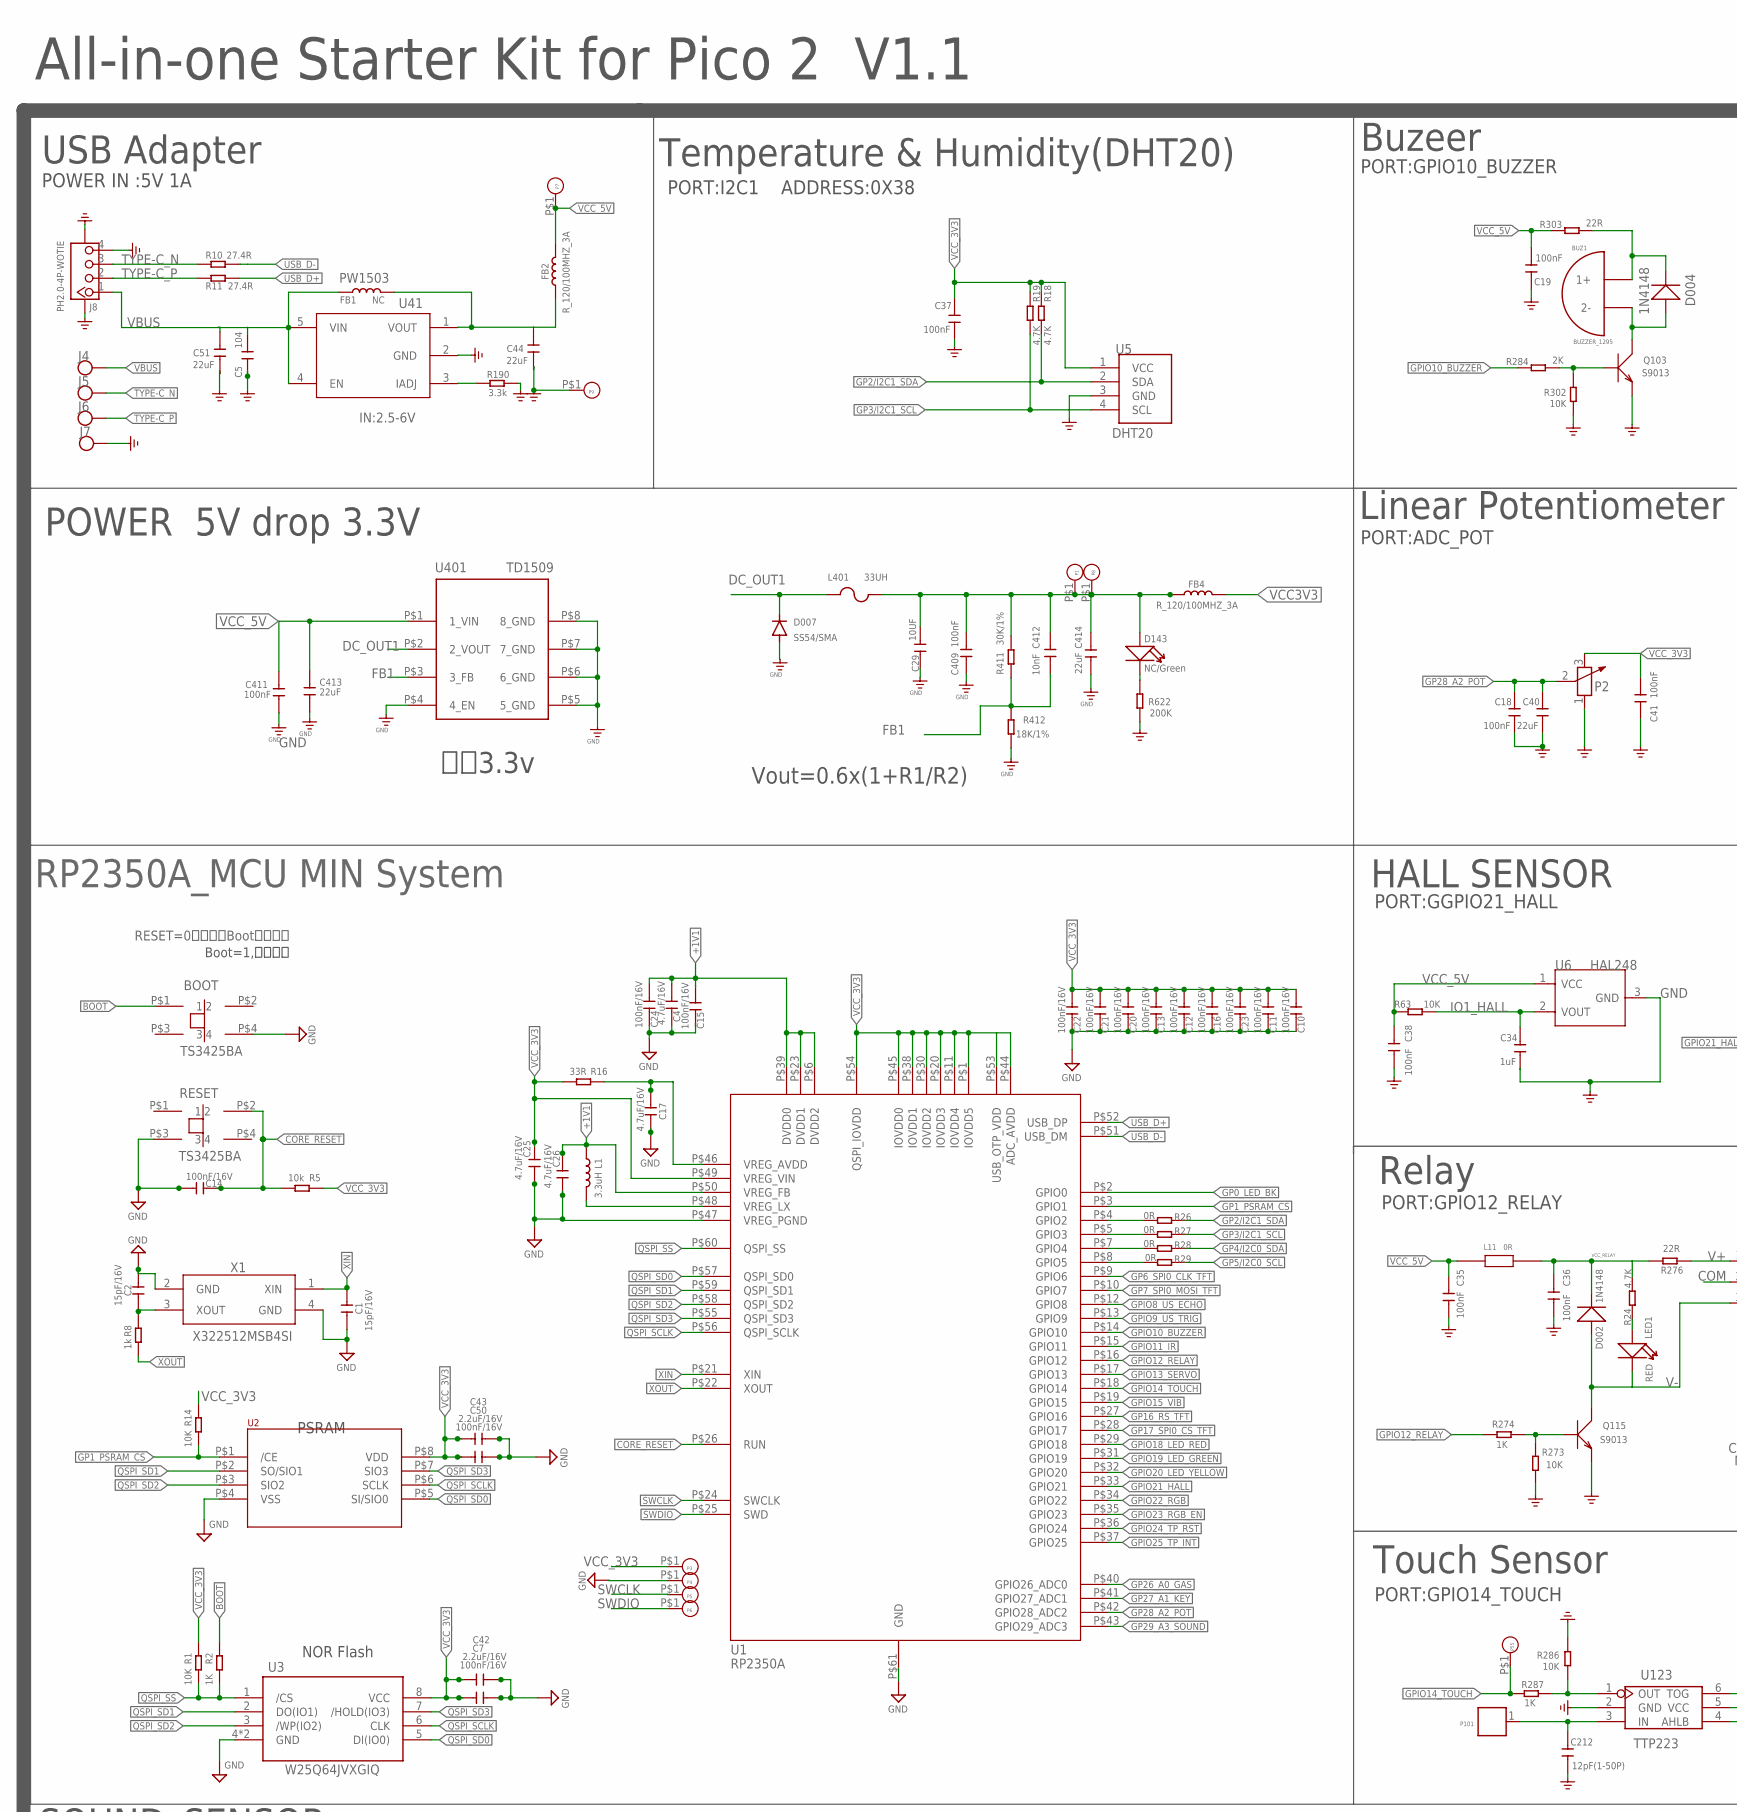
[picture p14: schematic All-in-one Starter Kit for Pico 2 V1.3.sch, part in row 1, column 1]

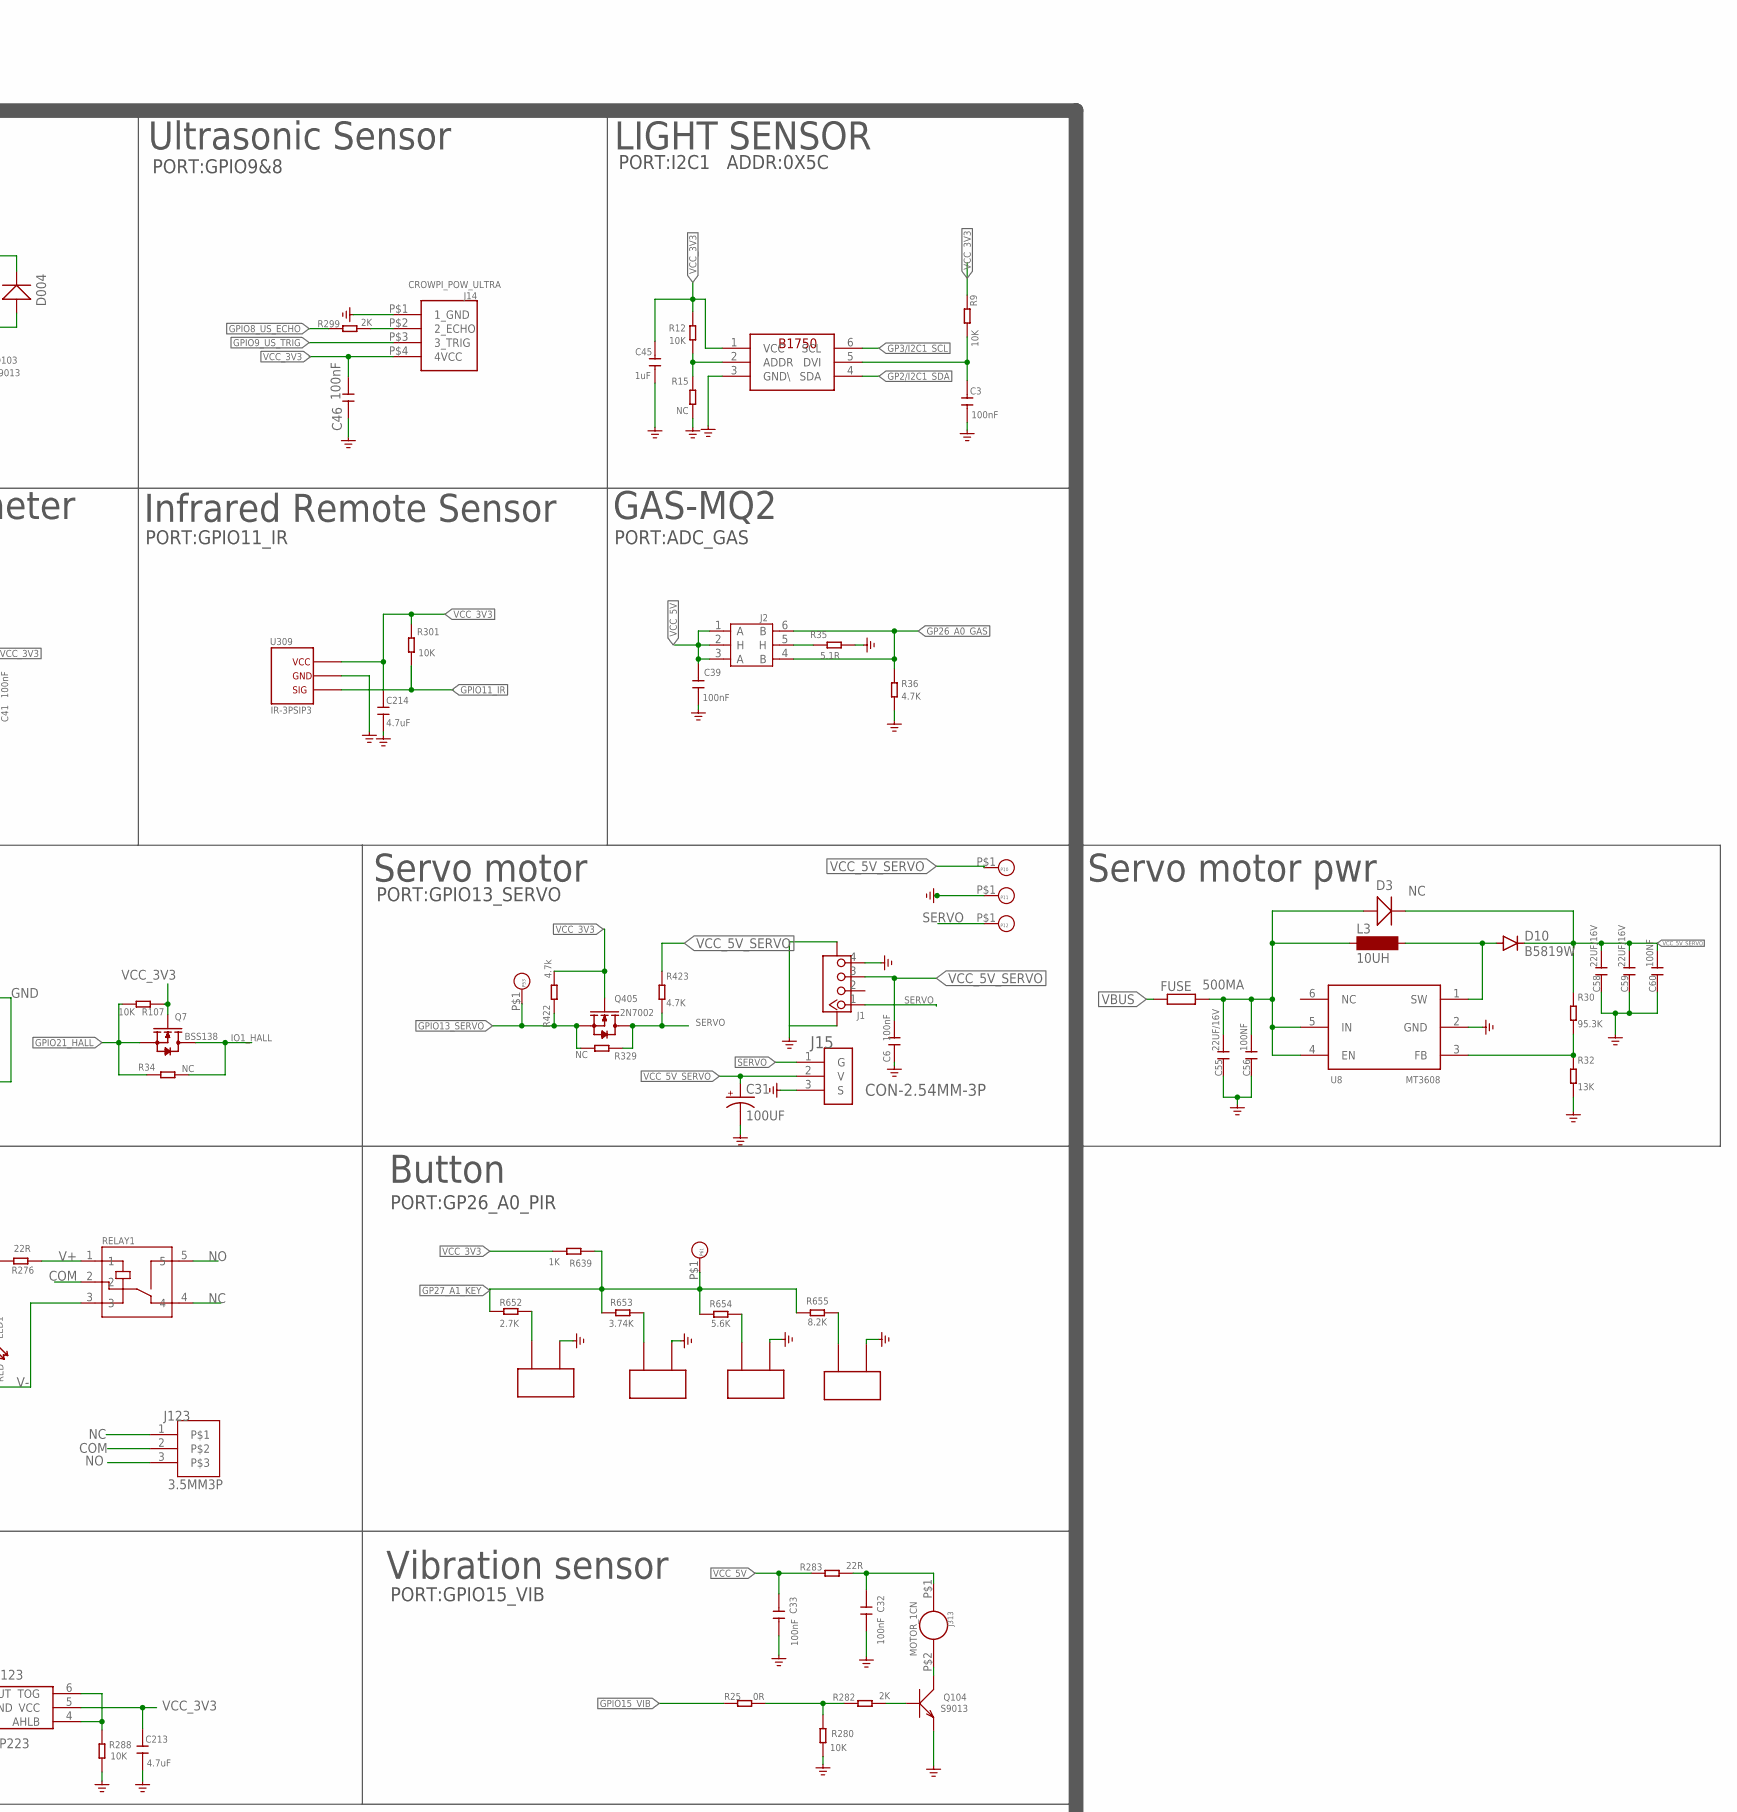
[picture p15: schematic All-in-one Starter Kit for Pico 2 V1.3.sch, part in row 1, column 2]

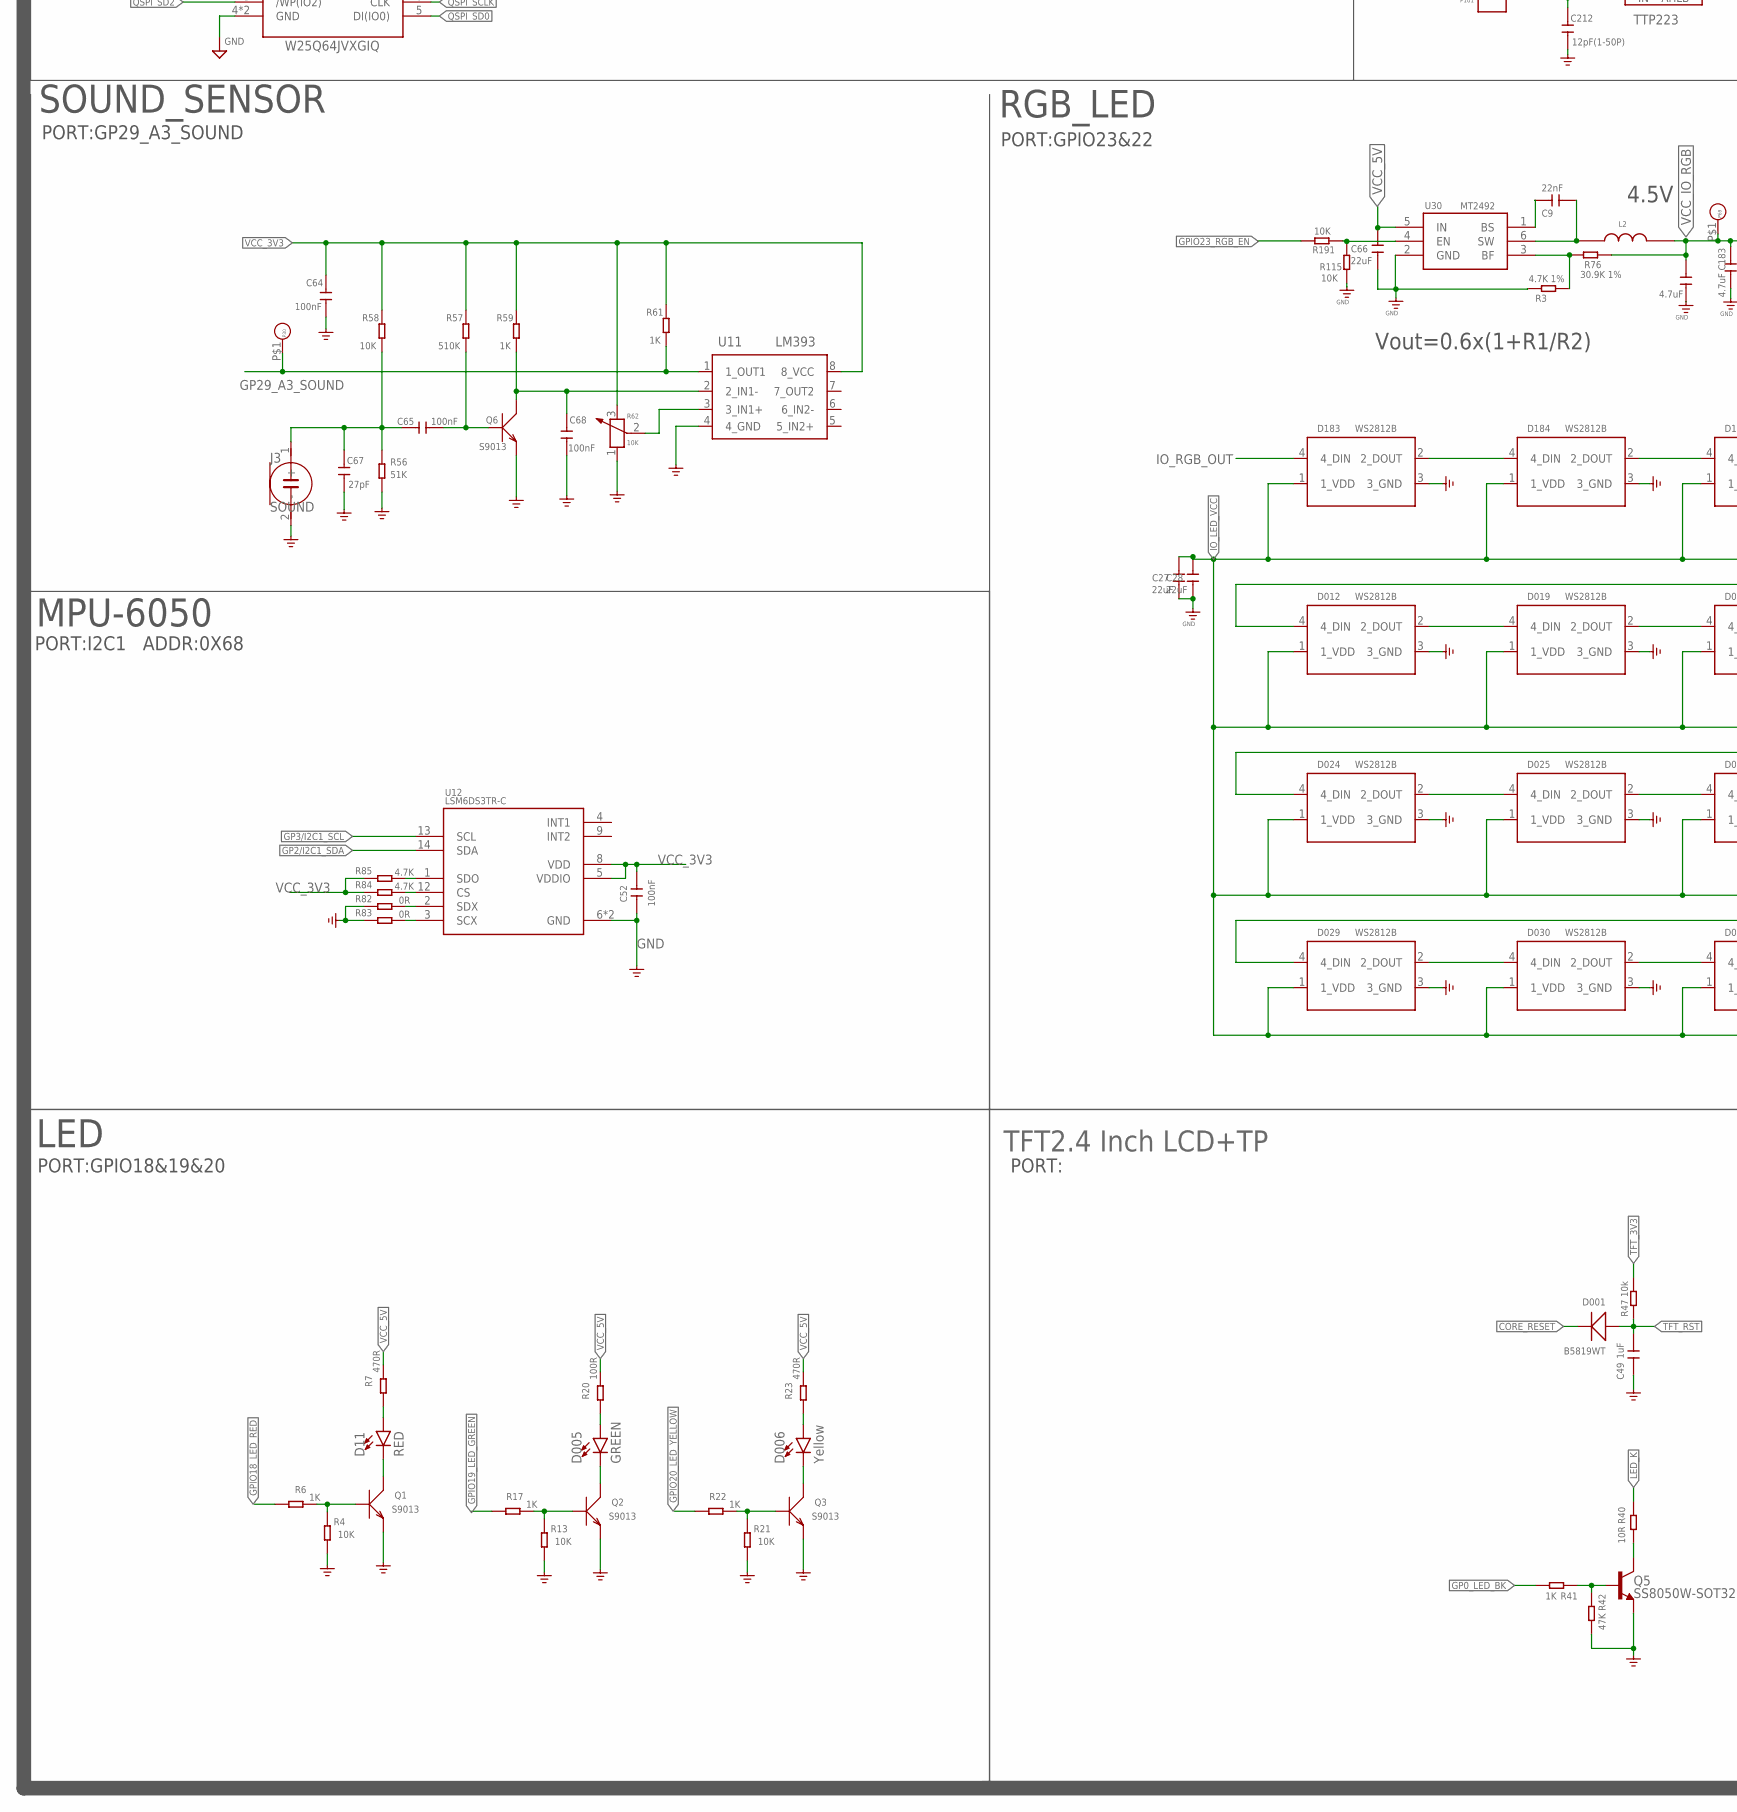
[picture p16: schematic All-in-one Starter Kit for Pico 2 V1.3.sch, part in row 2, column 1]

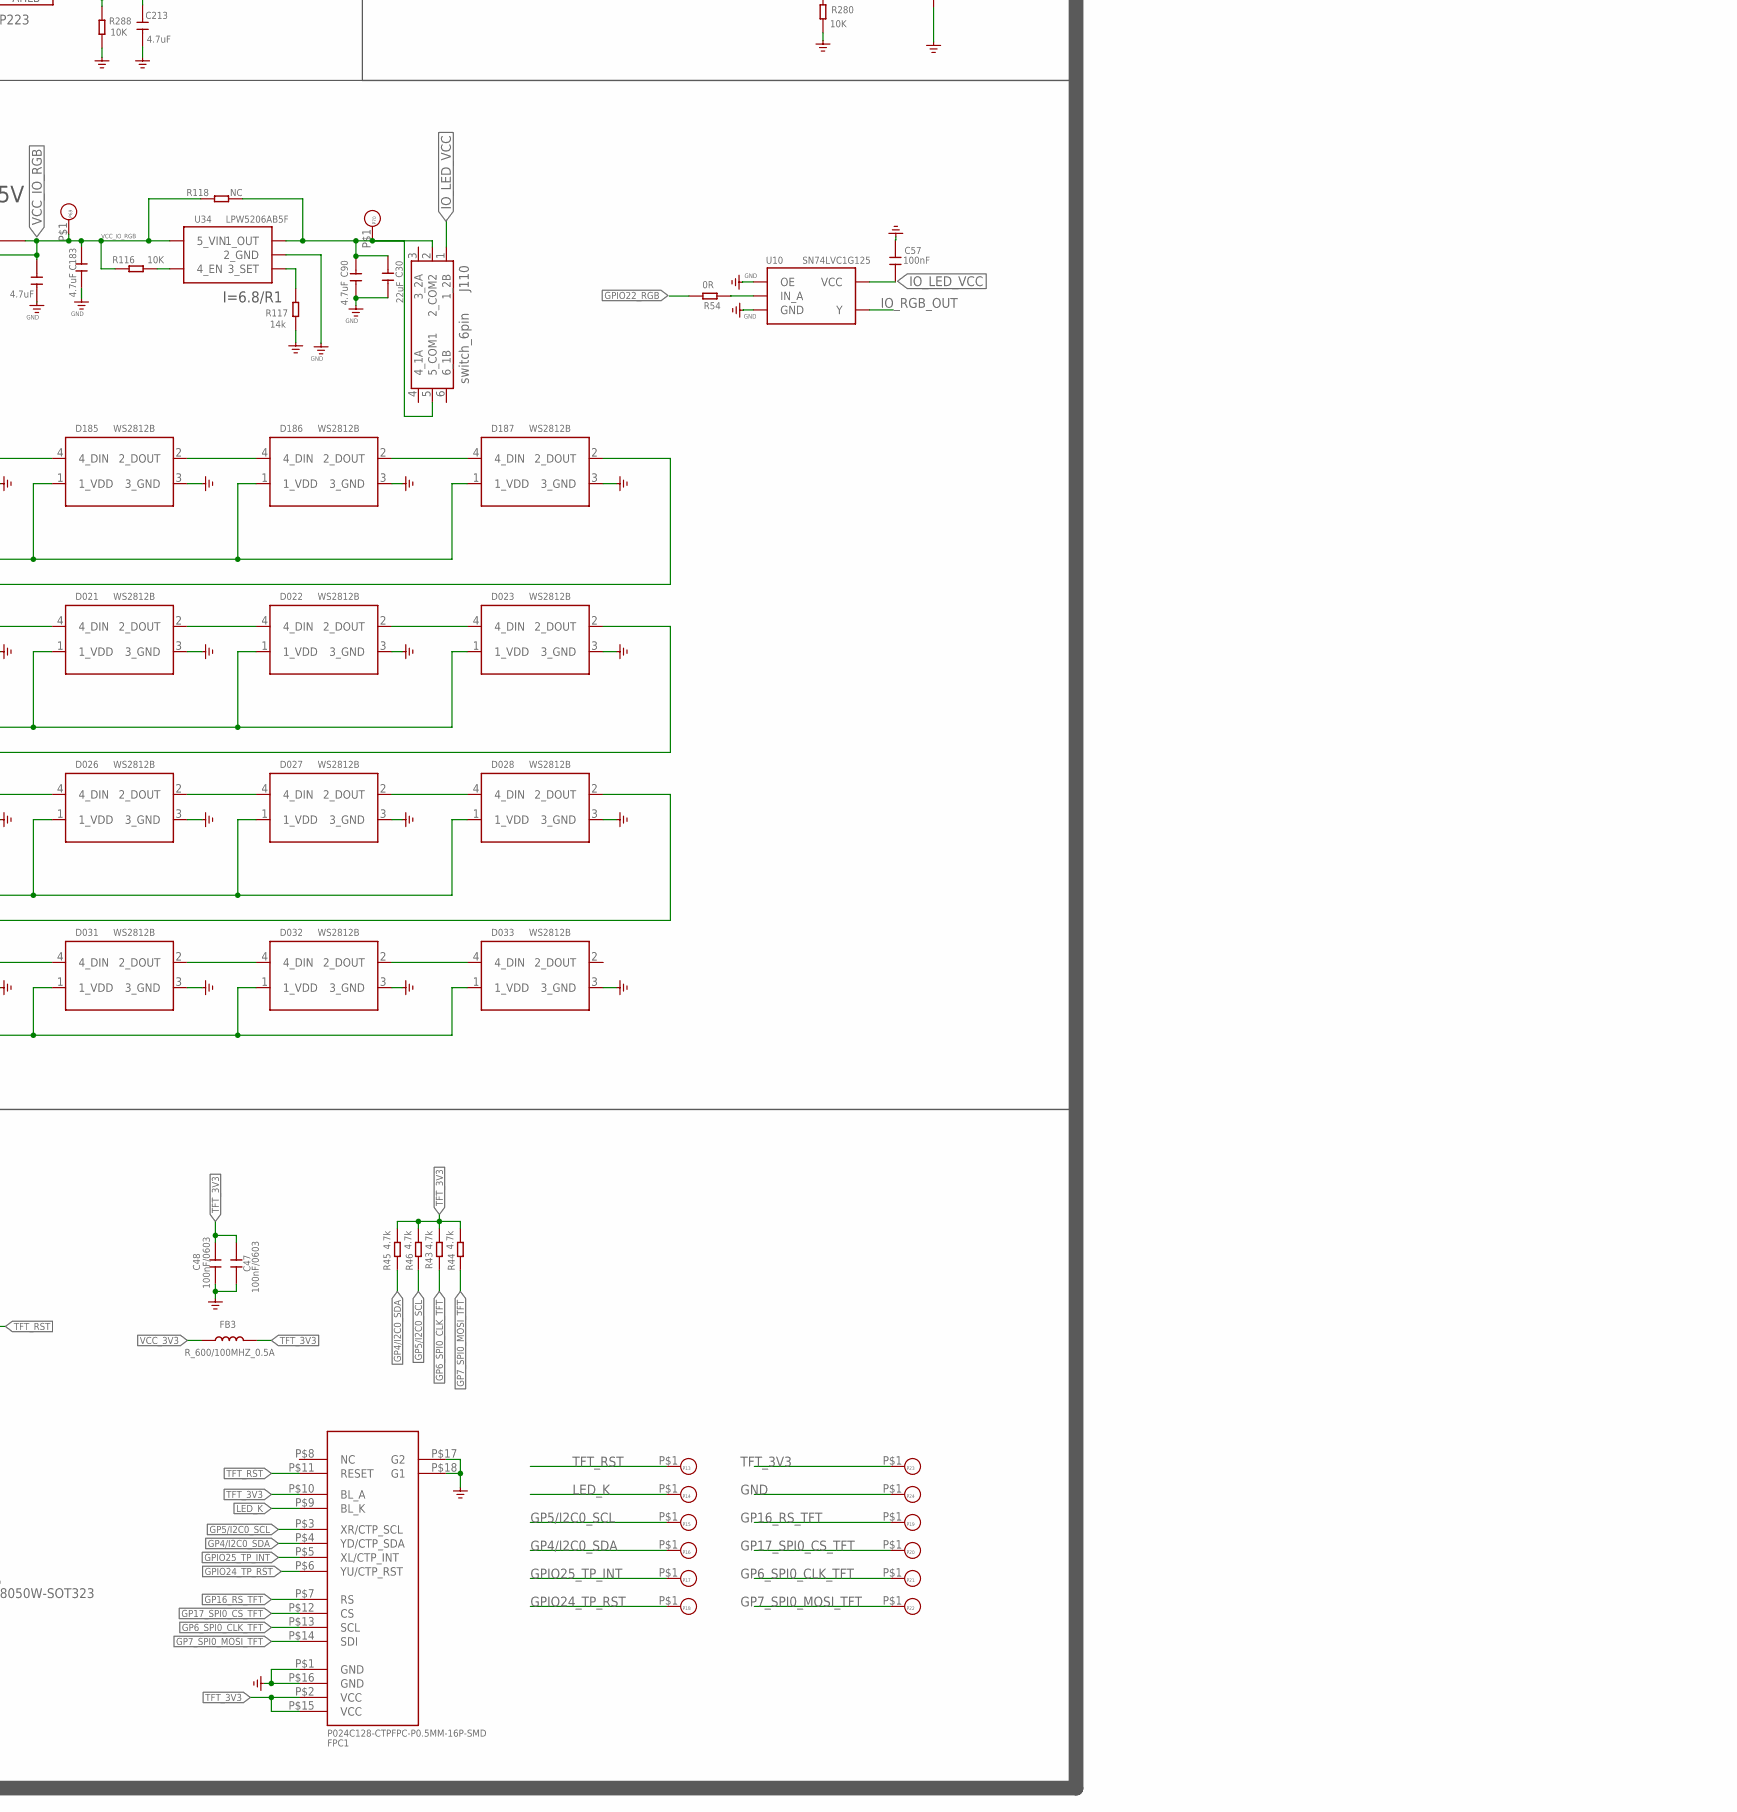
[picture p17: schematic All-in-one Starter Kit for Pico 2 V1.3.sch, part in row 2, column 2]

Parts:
BOOT: TS3425BA; SMD_KEY4.2*3.*.2.5
BUZ1: BUZZER_1295; BUZZER-D12MM-DIP2
C1, C2: 15pF/16V; C0603
C3, C6, C18, C19, C32, C33, C35, C36, C37, C38, C39, C41, C46, C52, C57, C64, C65, C68, C409, C411: 100nF; C0603
C4, C17, C25, C26: 4.7uF/16V; C0603
C5: 104; C0805
C7, C10, C11, C12, C13, C14, C15, C16, C20, C21, C22, C23, C24, C50: 100nF/16V; C0603
C8, C90, C183, C213, C214: 4.7uF; C0603
C9: 22nF; C0603
C27, C28, C30, C44, C51, C66, C413, C414: 22uF; C0805
C29: 10UF; C0805
C31: 100UF; SANYO-OSCON_SMD_C6
C34, C45, C49: 1uF; C0603
C40: 22uF; C0603
C42, C43: 2.2uF/16V; C0603
C47, C48: 100nF/0603; C0603
C55, C58, C59: 22UF/16V; C0603
C56, C60: 100NF; C0603
C67: 27pF; C0603
C212: 12pF(1-50P); C0603
C412: 10nF; C0603
D001: B5819WT; D_SOD523
D002, D004: 1N4148; D_SOD123
D3: NC; D_SOD123FL
D005: GREEN; LED-8MM
D006: Yellow; LED-8MM
D007: SS54/SMA; DIODE_DO-214AC
D10: B5819W; SOD-123_MINI-SMA
D11: RED; LED-8MM
D012, D019, D021, D022, D023, D024, D025, D026, D027, D028, D029, D030, D031, D032, D033, D183, D184, D185, D186, D187: WS2812B; LED_RGB_WS2812_3535
D143: NC/Green; LED_0603_SMT
FB1: NC; L0805
FB2, FB4: R_120/100MHZ_3A; L0805
FB3: R_600/100MHZ_0.5A; L0603
FPC1: P024C128-CTPFPC-P0.5MM-16P-SMD; FPC-P0.5MM-16P-SMD
FUSE: 500MA; R0805
J1: A_XBJ_CONNECTOR_TWIG-4P-2.0-SMD-FEMALE-REINFORCE9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; A_XBJ_CONNECTOR_4P-SMD-2.0-90D
J2: MQ-SOCKET; MQ2
J3: SOUND; TEMPLATE_2P-D8.9MM
J4, J5, J6, J7: TP-SMDTP-SMD-2X4MM; TP-SMD-2X4MM
J8: PH2.0-4P-WOTIE; PH2.0-4P
J14: CROWPI_POW_ULTRA
J15: CON-2.54MM-3P; CON-PZ-2.54MM-1*3P-WT
J110: switch_6pin; SWITCH_6PIN_2P
J123: 3.5MM3P; 3.5MM*3P
J313: MOTOR_1CN; MOTOR_1CM
K1, K2, K3, K4: BUTTON_2P
L1: 3.3uH; SMD,1.6X2MM
L2: CD32_950MA; CD32
L3: 10UH; MS42
L11: 0R; 201209
L401: 33UH; L773
LED1: RED; DISCRETE_LED-0603
P1, P3, P4, P5, P6, P7, P8, P9, P10, P11, P12, P13, P14, P15, P16, P17, P18, P19, P20, P21, P22, P23, P24, P30, P53, P55, P61, P69, P70: PADPAD-1.0MM; PAD-1.0MM
P2: R-POTENTIOMETER; 3P-SQUA-45.6X10X5.8H
P101: KEY; 1P-D450
Q1, Q2, Q3, Q6, Q103, Q104, Q115: S9013; SOT23@1
Q5: SS8050W-SOT323; MOS_SOT323
Q7: BSS138; SOT23
Q405: 2N7002; SOT23
R1, R4, R9, R12, R13, R14, R21, R58, R63, R107, R115, R116, R191, R273, R280, R286, R288, R301, R302: 10K; R0603
R2, R6, R17, R22, R41, R59, R61, R274, R287, R639: 1K; R0603
R3: 4.7K 1%; R0603
R5, R47: 10k; R0603
R7, R23: 470R; R0603
R8: 1k; R0603
R10, R11: 27.4R; R0603
R15, R34, R118, R329: NC; R0603
R16: 33R; R0603
R18, R19, R24, R36, R84, R85, R423: 4.7K; R0603
R20: 100R; R0603
R25, R26, R27, R28, R29, R54, R82, R83: 0R; R0603
R30: 95.3K; R0603
R32: 13K; R0603
R35: 5.1R; R0603
R40: 10R; R0603
R42: 47K; R0603
R43, R44, R45, R46, R422: 4.7k; R0603
R56: 51K; R0603
R57: 510K; R0603
R62: 10K; 3P-SMD-SQUA-3.6X3.3
R76: 30.9K 1%; R0603
R117: 14k; R0603
R190: 3.3k; R0603
R276, R283, R303: 22R; R0603
R282, R284, R299: 2K; R0603
R411: 30K/1%; R0603
R412: 18K/1%; R0603
R622: 200K; R0603
R652: 2.7K; R0603
R653: 3.74K; R0603
R654: 5.6K; R0603
R655: 8.2K; R0603
RELAY1: RELAY-SRD; REY5-6-19.1X15.5X15.3MM
RESET: TS3425BA; SMD_KEY4.2*3.*.2.5
U1: RP2350A; QFN-60_7X7MM
U2: APS6404L; SOP-8L
U3: W25Q64JVXGIQ; W25QXX-XSON-8-EP(4X4)
U5: DHT20; CROWTAIL-DHT20-V1.0-20211013_DHT20
U6: HAL248; SOT-23W
U7: BH1750; BH1750-WSOF-6
U8: MT3608; DBV_R-PDSO-G6
U10: SN74LVC1G125; SOT23-5
U11: LM393; SOP8@1
U12: LSM6DS3TR-C; LGA-14L
U30: MT2492; MT2492-SOT23-6
U34: LPW5206AB5F; IC_SOT23-5
U41: PW1503; SOT23-5
U123: TTP223; SOT23-6L
U309: IR-3PSIP3; VS1838B-SIP3
U401: TD1509
X1: X322512MSB4SI; A_XBJ_SMD3225

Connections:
+1V1: C4.1, C15.1, C24.1, C26.2, L1.P$1 (1), U1.P$6 (DVDD2), U1.P$23 (DVDD1), U1.P$39 (DVDD0), U1.P$50 (VREG_FB)
BOOT: BOOT.P$1 (1), R2.2
COM: J123.2, RELAY1.2
CORE_RESET: C14.2, D001.-, R5.1, RESET.P$2 (2), U1.P$26 (RUN)
DC_OUT1: D007.C, L401.1, U401.P$2 (2_VOUT)
FB1: C412.1, R411.1, R412.2, U401.P$3 (3_FB)
GND: BOOT.P$4 (4), C1.1, C2.2, C3.1, C4.2, C5.1, C6.1, C7.1, C8.2, C10.2, C11.2, C12.2, C13.2, C14.1, C15.2, C16.2, C17.2, C18.1, C19.2, C20.2, C21.2, C22.2, C23.2, C24.2, C25.1, C26.1, C27.2, C28.2, C29.2, C30.2, C31.-, C32.1, C33.1, C34.1, C35.1, C36.1, C37.1, C38.1, C39.1, C40.1, C41.1, C42.1, C43.1, C44.2, C45.1, C46.2, C47.1, C48.1, C49.1, C50.1, C51.2, C52.1, C55.1, C56.1, C57.2, C58.1, C59.1, C60.1, C64.1, C66.2, C67.1, C68.1, C90.2, C183.2, C212.1, C213.1, C214.1, C409.1, C411.1, C413.2, C414.2, D007.A, D012.3 (3_GND), D019.3 (3_GND), D021.3 (3_GND), D022.3 (3_GND), D023.3 (3_GND), D024.3 (3_GND), D025.3 (3_GND), D026.3 (3_GND), D027.3 (3_GND), D028.3 (3_GND), D029.3 (3_GND), D030.3 (3_GND), D031.3 (3_GND), D032.3 (3_GND), D033.3 (3_GND), D183.3 (3_GND), D184.3 (3_GND), D185.3 (3_GND), D186.3 (3_GND), D187.3 (3_GND), FPC1.P$1 (GND), FPC1.P$16 (GND), FPC1.P$17 (G2), FPC1.P$18 (G1), J1.4, J1.SS1, J1.SS2, J3.2 (-), J7.1, J8.4, J8.5 (SS1), J8.6 (SS2), J14.P$1 (1_GND), J15.3 (S), K1.P$1, K2.P$1, K3.P$1, K4.P$1, P2.1, P4.P$1, P9.P$1, P11.P$1, P24.P$1, Q1.2 (E), Q2.2 (E), Q3.2 (E), Q5.2 (E), Q6.2 (E), Q103.2 (E), Q104.2 (E), Q115.2 (E), R3.1, R4.1, R13.1, R15.1, R21.1, R32.2, R35.1, R36.2, R42.2, R56.2, R62.1, R82.1, R83.1, R115.2, R117.2, R190.2, R273.1, R280.1, R286.2, R288.2, R302.1, R412.1, R622.2, RESET.P$3 (3), U1.P$47 (VREG_PGND), U1.P$61 (GND), U2.P$4 (VSS), U3.4 (GND), U3.EP (GND), U5.3 (GND), U6.3 (GND), U7.3 (GND\), U8.2 (GND), U10.1 (OE), U10.3 (GND), U11.4 (4_GND), U12.6 (GND), U12.7 (GND), U30.2 (GND), U34.2 (2_GND), U41.2 (GND), U123.2 (GND), U309.2, U401.P$4 (4_EN), U401.P$5 (5_GND), U401.P$6 (6_GND), U401.P$7 (7_GND), U401.P$8 (8_GND), X1.2 (GND), X1.4 (GND)
GP0_LED_BK: R41.2, U1.P$2 (GPIO0)
GP1_PSRAM_CS: R14.1, U1.P$3 (GPIO1), U2.P$1 (/CE)
GP2/I2C1_SDA: R18.2, R26.2, U5.2 (SDA), U7.4 (SDA), U12.14 (SDA)
GP3/I2C1_SCL: R19.2, R27.2, U5.4 (SCL), U7.6 (SCL), U12.13 (SCL)
GP4/I2C0_SDA: FPC1.P$4 (YD/CTP_SDA), P16.P$1, R28.2, R45.1
GP5/I2C0_SCL: FPC1.P$3 (XR/CTP_SCL), P15.P$1, R29.2, R46.1
GP6_SPI0_CLK_TFT: FPC1.P$13 (SCL), P21.P$1, R43.1, U1.P$9 (GPIO6)
GP7_SPI0_MOSI_TFT: FPC1.P$14 (SDI), P22.P$1, R44.1, U1.P$10 (GPIO7)
GP16_RS_TFT: FPC1.P$7 (RS), P19.P$1, U1.P$27 (GPIO16)
GP17_SPI0_CS_TFT: FPC1.P$12 (CS), P20.P$1, U1.P$28 (GPIO17)
GP26_A0_GAS: J2.4 (B), J2.6 (B), R36.1, U1.P$40 (GPIO26_ADC0)
GP27_A1_KEY: P61.P$1, R639.2, R652.2, R653.2, R654.2, R655.2, U1.P$41 (GPIO27_ADC1)
GP28_A2_POT: C18.2, C40.2, P2.2 (3), U1.P$42 (GPIO28_ADC2)
GP29_A3_SOUND: P30.P$1, R61.1, U1.P$43 (GPIO29_ADC3), U11.1 (1_OUT1)
GPIO8_US_ECHO: R299.2, U1.P$12 (GPIO8)
GPIO9_US_TRIG: J14.P$3 (3_TRIG), U1.P$13 (GPIO9)
GPIO10_BUZZER: R284.1, U1.P$14 (GPIO10)
GPIO11_IR: R301.2, U1.P$15 (GPIO11), U309.3
GPIO12_RELAY: R274.2, U1.P$16 (GPIO12)
GPIO13_SERVO: P53.P$1, Q405.2 (S), R329.2, R422.1, U1.P$17 (GPIO13)
GPIO14_TOUCH: P55.P$1, R287.2, U1.P$18 (GPIO14)
GPIO15_VIB: R25.2, U1.P$19 (GPIO15)
GPIO18_LED_RED: R6.2, U1.P$29 (GPIO18)
GPIO19_LED_GREEN: R17.2, U1.P$31 (GPIO19)
GPIO20_LED_YELLOW: R22.2, U1.P$32 (GPIO20)
GPIO21_HALL: Q7.2 (S), R34.1, R107.1, U1.P$33 (GPIO21)
GPIO22_RGB: R54.1, U1.P$34 (GPIO22)
GPIO23_RGB_EN: R191.1, U1.P$35 (GPIO23)
GPIO24_TP_RST: FPC1.P$6 (YU/CTP_RST), P18.P$1, U1.P$36 (GPIO24)
GPIO25_TP_INT: FPC1.P$5 (XL/CTP_INT), P17.P$1, U1.P$37 (GPIO25)
IN1: C212.2, P101.1, U123.3 (IN)
IO0_VIB: R25.1, R280.2, R282.1
IO1_HALL: C34.2, Q7.3 (D), R34.2, R63.1, U6.2 (VOUT)
IO_LED_V: C30.1, C90.1, J110.2 (2_COM2), J110.5 (5_COM1), P70.P$1, R118.2, U34.1 (1_OUT)
IO_LED_VCC: C27.1, C28.1, C57.1, D012.1 (1_VDD), D019.1 (1_VDD), D021.1 (1_VDD), D022.1 (1_VDD), D023.1 (1_VDD), D024.1 (1_VDD), D025.1 (1_VDD), D026.1 (1_VDD), D027.1 (1_VDD), D028.1 (1_VDD), D029.1 (1_VDD), D030.1 (1_VDD), D031.1 (1_VDD), D032.1 (1_VDD), D033.1 (1_VDD), D183.1 (1_VDD), D184.1 (1_VDD), D185.1 (1_VDD), D186.1 (1_VDD), D187.1 (1_VDD), J110.1 (1_2B), U10.5 (VCC)
IO_RGB_OUT: D183.4 (4_DIN), U10.4 (Y)
IO_RGB_OUT1: D012.4 (4_DIN), D187.2 (2_DOUT)
IO_RGB_OUT2: D023.2 (2_DOUT), D024.4 (4_DIN)
IO_RGB_OUT3: D028.2 (2_DOUT), D029.4 (4_DIN)
LED_K: FPC1.P$9 (BL_K), P14.P$1, R40.2
unnamed: D012.2 (2_DOUT), D019.4 (4_DIN)
unnamed: C2.1, R8.2, X1.3 (XOUT)
unnamed: D019.2 (2_DOUT), D021.4 (4_DIN)
unnamed: R26.1, U1.P$4 (GPIO2)
unnamed: Q2.1 (B), R13.2, R17.1
unnamed: C17.1, R16.2, U1.P$46 (VREG_AVDD)
unnamed: D005.2 (C), Q2.3 (C)
unnamed: R27.1, U1.P$5 (GPIO3)
unnamed: C3.2, R9.2, U7.5 (DVI)
unnamed: D005.1 (A), R20.2
unnamed: Q3.1 (B), R21.2, R22.1
unnamed: L1.P$2 (2), U1.P$48 (VREG_LX)
unnamed: D021.2 (2_DOUT), D022.4 (4_DIN)
unnamed: Q1.1 (B), R4.2, R6.1
unnamed: D11.2 (C), Q1.3 (C)
unnamed: D11.1 (A), R7.2
unnamed: D006.2 (C), Q3.3 (C)
unnamed: D006.1 (A), R23.2
unnamed: LED1.+, R24.1
unnamed: D022.2 (2_DOUT), D023.4 (4_DIN)
unnamed: Q5.1 (B), R41.1, R42.1
unnamed: D024.2 (2_DOUT), D025.4 (4_DIN)
unnamed: J2.5 (H), R35.2
unnamed: D025.2 (2_DOUT), D026.4 (4_DIN)
unnamed: D026.2 (2_DOUT), D027.4 (4_DIN)
unnamed: D027.2 (2_DOUT), D028.4 (4_DIN)
unnamed: R82.2, U12.2 (SDX)
unnamed: D029.2 (2_DOUT), D030.4 (4_DIN)
unnamed: D030.2 (2_DOUT), D031.4 (4_DIN)
unnamed: D031.2 (2_DOUT), D032.4 (4_DIN)
unnamed: D032.2 (2_DOUT), D033.4 (4_DIN)
unnamed: C55.2, C56.2, D3.+, FUSE.2, L3.1, U8.4 (EN), U8.5 (IN)
unnamed: R28.1, U1.P$7 (GPIO4)
unnamed: R12.1, R15.2, U7.2 (ADDR)
unnamed: R30.2, R32.1, U8.3 (FB)
unnamed: D10.A, L3.2, U8.1 (SW)
unnamed: R190.1, U41.3 (IADJ)
unnamed: R29.1, U1.P$8 (GPIO5)
unnamed: J313.P$2, Q104.3 (C)
unnamed: Q5.3 (C), R40.1
unnamed: R83.2, U12.3 (SCX)
unnamed: R84.2, U12.12 (CS)
unnamed: R54.2, U10.2 (IN_A)
unnamed: C65.1, Q6.1 (B), R57.1
unnamed: C68.2, Q6.3 (C), R59.1, U11.2 (2_IN1-)
unnamed: R62.2 (3), U11.3 (3_IN1+)
unnamed: C65.2, C67.2, J3.1 (+), R56.1, R58.1
unnamed: R85.2, U12.1 (SDO)
unnamed: D143.2 (2_K), R622.1
unnamed: R115.1, R191.2, U30.4 (EN)
unnamed: K1.P$2, R652.1
unnamed: K2.P$2, R653.1
unnamed: K3.P$2, R654.1
unnamed: K4.P$2, R655.1
unnamed: C9.1, L2.1, U30.6 (SW)
unnamed: R3.2, R76.1, U30.3 (BF)
unnamed: C9.2, U30.1 (BS)
unnamed: R117.1, U34.3 (3_SET)
unnamed: R116.1, U34.4 (4_EN)
unnamed: Q115.1 (B), R273.2, R274.1
unnamed: C32.2, J313.P$1, R283.2
unnamed: R288.1, U123.4 (AHLB), U123.6 (TOG)
unnamed: Q104.1 (B), R282.2
unnamed: R286.1, R287.1, U123.1 (OUT)
unnamed: J14.P$2 (2_ECHO), R299.1
unnamed: Q103.1 (B), R284.2, R302.2
unnamed: BUZ1.2 (2-), D004.+, Q103.3 (C)
unnamed: BUZ1.1 (1+), D004.-, R303.2
unnamed: D183.2 (2_DOUT), D184.4 (4_DIN)
unnamed: D184.2 (2_DOUT), D185.4 (4_DIN)
unnamed: D185.2 (2_DOUT), D186.4 (4_DIN)
unnamed: D186.2 (2_DOUT), D187.4 (4_DIN)
NC: J123.1, RELAY1.4
NO: J123.3, RELAY1.5
QSPI_SCLK: U1.P$56 (QSPI_SCLK), U2.P$6 (SCLK), U3.6 (CLK)
QSPI_SD0: U1.P$57 (QSPI_SD0), U2.P$5 (SI/SIO0), U3.5 (DI(IO0))
QSPI_SD1: U1.P$59 (QSPI_SD1), U2.P$2 (SO/SIO1), U3.2 (DO(IO1))
QSPI_SD2: U1.P$58 (QSPI_SD2), U2.P$3 (SIO2), U3.3 (/WP(IO2))
QSPI_SD3: U1.P$55 (QSPI_SD3), U2.P$7 (SIO3), U3.7 (/HOLD(IO3))
QSPI_SS: R1.1, R2.1, U1.P$60 (QSPI_SS), U3.1 (/CS)
SERVO: J1.1, J15.1 (G), P12.P$1, Q405.3 (D), R329.1, R423.2
SWCLK: P5.P$1, U1.P$24 (SWCLK)
SWDIO: P6.P$1, U1.P$25 (SWD)
TFT_3V3: C47.2, C48.2, FB3.2, FPC1.P$2 (VCC), FPC1.P$10 (BL_A), FPC1.P$15 (VCC), P23.P$1, R43.2, R44.2, R45.2, R46.2, R47.2
TFT_RST: C49.2, D001.+, FPC1.P$11 (RESET), P13.P$1, R47.1
TYPE-C_N: J5.1, J8.3, R10.1
TYPE-C_P: J6.1, J8.2, R11.1
USB_D+: R11.2, U1.P$52 (USB_DP)
USB_D-: R10.2, U1.P$51 (USB_DM)
V+: R276.2, RELAY1.1
V-: D002.+, LED1.-, Q115.3 (C), RELAY1.3
VBUS: C5.2, C51.1, FB1.1, FUSE.1, J4.1, J8.1, U41.4 (EN), U41.5 (VIN)
VCC: C44.1, FB1.2, FB2.1, U41.1 (VOUT)
VCC3V3: C29.1, C409.2, C412.2, C414.1, D143.1 (1_A), FB4.1, L401.2, P1.P$1, P8.P$1, R411.2
VCC_3V3: C7.2, C10.1, C11.1, C12.1, C13.1, C16.1, C20.1, C21.1, C22.1, C23.1, C25.2, C37.2, C41.2, C42.2, C43.2, C45.2, C46.1, C50.2, C52.2, C64.2, C213.2, C214.2, FB3.1, FB4.2, J14.P$4 (4VCC), P2.3 (2), P3.P$1, Q7.1 (G), Q405.1 (G), R1.2, R5.2, R9.1, R12.2, R14.2, R16.1, R18.1, R19.1, R57.2, R58.2, R59.2, R61.2, R62.3 (2), R84.1, R85.1, R107.2, R301.1, R422.2, R639.1, U1.P$1 (IOVDD5), U1.P$11 (IOVDD4), U1.P$20 (IOVDD3), U1.P$30 (IOVDD2), U1.P$38 (IOVDD1), U1.P$44 (ADC_AVDD), U1.P$45 (IOVDD0), U1.P$49 (VREG_VIN), U1.P$53 (USB_OTP_VDD), U1.P$54 (QSPI_IOVDD), U2.P$8 (VDD), U3.8 (VCC), U5.1 (VCC), U7.1 (VCC), U11.8 (8_VCC), U12.5 (VDDIO), U12.8 (VDD), U123.5 (VCC), U309.1
VCC_5V: C19.1, C33.2, C35.2, C38.2, C39.2, C66.1, C411.2, C413.1, FB2.2, J2.2 (H), J2.3 (A), L11.1, P7.P$1, R7.1, R20.1, R23.1, R63.2, R283.1, R303.1, U6.1 (VCC), U30.5 (IN), U401.P$1 (1_VIN)
VCC_5V_SERVO: C6.2, C31.+, C58.2, C59.2, C60.2, D3.-, D10.C, J1.3, J15.2 (V), P10.P$1, R30.1, R423.1
VCC_IO_RGB: C8.1, C183.1, L2.2, P69.P$1, R76.2, R116.2, R118.1, U34.5 (5_VIN)
VCC_RELAY: C36.2, D002.-, L11.2, R24.2, R276.1
XIN: C1.2, U1.P$21 (XIN), X1.1 (XIN)
XOUT: R8.1, U1.P$22 (XOUT)

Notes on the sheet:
USB Adapter
RP2350A_MCU MIN System
RESET=0时，按下Boot下载模式
Temperature & Humidity(DHT20)
POWER 5V drop 3.3V
Boot=1,正常运行
NOR Flash
PORT:I2C1 ADDRESS:0X38
Buzeer
PORT:GPIO10_BUZZER
Ultrasonic Sensor
PORT:GPIO9&8
LIGHT SENSOR
PORT:I2C1 ADDR:0X5C
Linear Potentiometer
PORT:ADC_POT
Button
PORT:GP26_A0_PIR
Infrared Remote Sensor
PORT:GPIO11_IR
Relay
PORT:GPIO12_RELAY
Servo motor
PORT:GPIO13_SERVO
TTP223
Touch Sensor
PORT:GPIO14_TOUCH
Vibration sensor
PORT:GPIO15_VIB
HALL SENSOR
PORT:GGPIO21_HALL
GAS-MQ2
PORT:ADC_GAS
All-in-one Starter Kit for Pico 2 V1.1
TFT2.4 Inch LCD+TP
RGB_LED
SOUND_SENSOR
PORT:GP29_A3_SOUND
MPU-6050
PORT:I2C1 ADDR:0X68

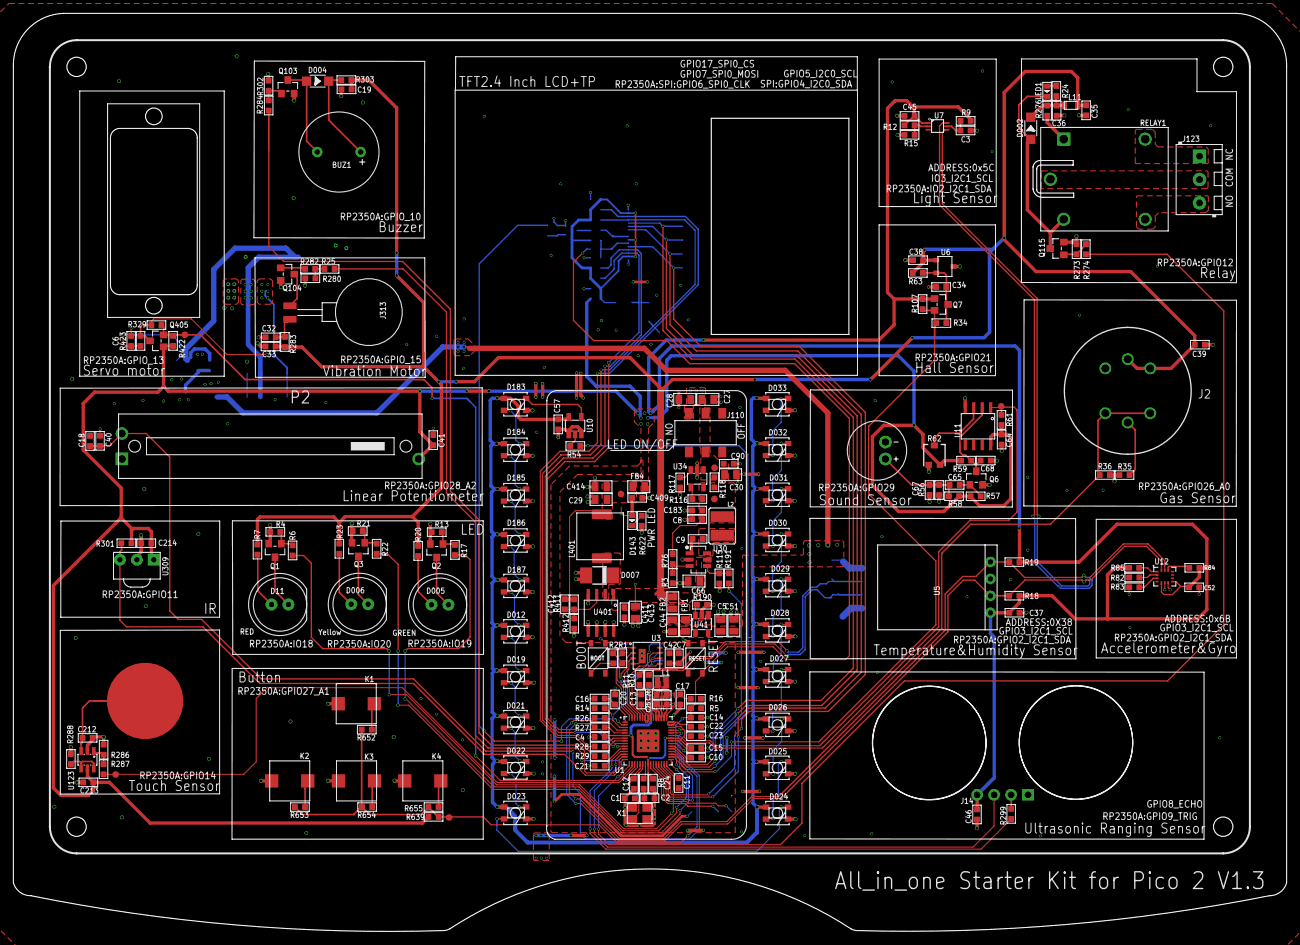
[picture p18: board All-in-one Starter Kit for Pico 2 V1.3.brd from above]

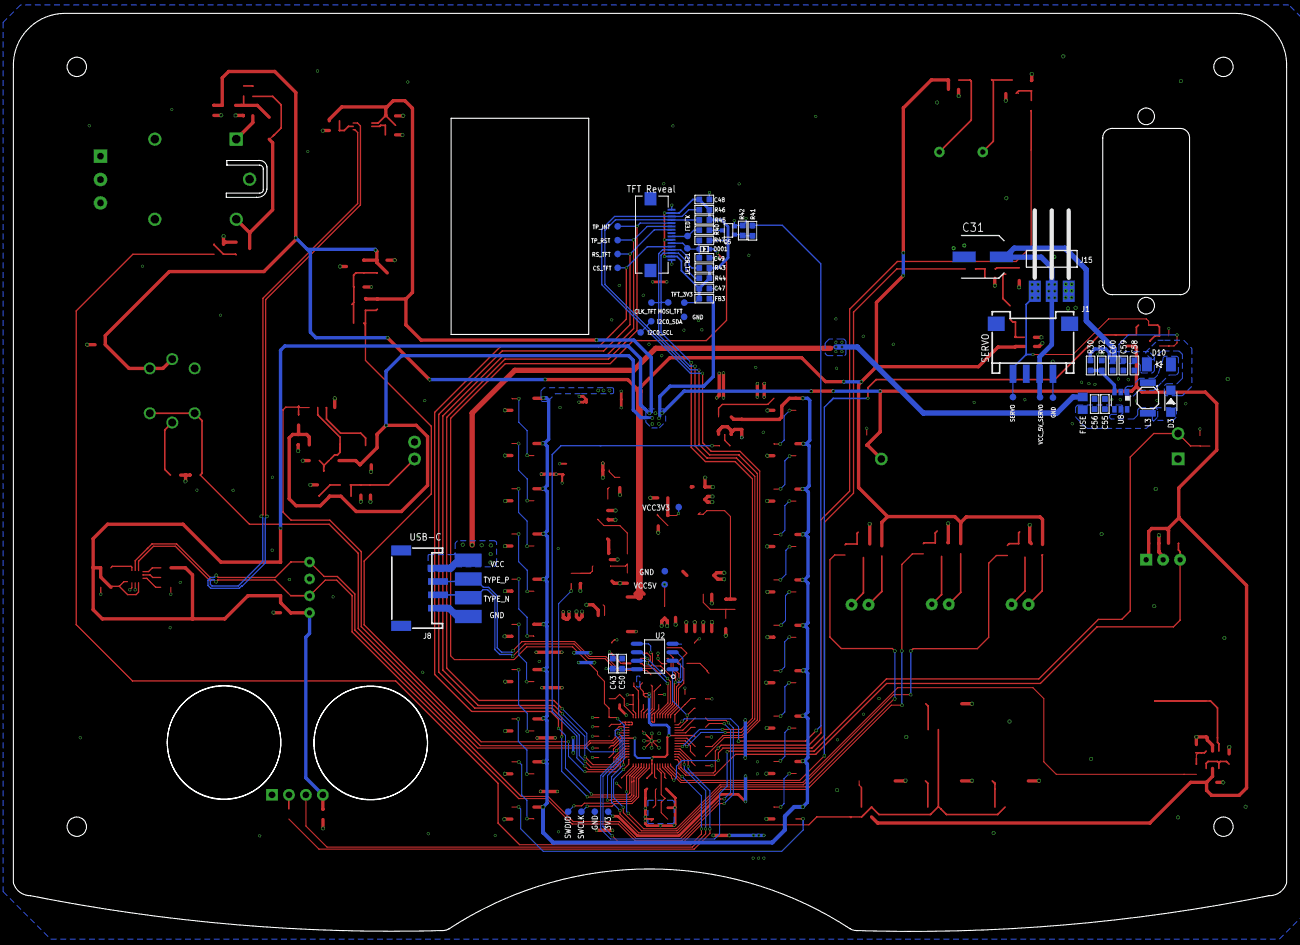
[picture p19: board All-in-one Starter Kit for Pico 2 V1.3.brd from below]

Board: 2 copper layers, 190.7 x 137.5 mm, 281 parts (60 on the bottom side), 148 nets.

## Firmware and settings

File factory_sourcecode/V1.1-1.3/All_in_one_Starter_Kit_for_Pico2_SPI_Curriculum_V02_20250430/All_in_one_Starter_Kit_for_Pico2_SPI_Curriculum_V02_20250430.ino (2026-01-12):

#include <lvgl.h>
#include "demos/lv_demos.h"
#include <Wire.h>
#include <LovyanGFX.hpp>
#include "ui.h"
#include <Ticker.h>  //Call the ticker. H Library
#include <Servo.h>
#include <Arduino.h>
#include <SPI.h>
#include <BH1750.h>
#include <Adafruit_NeoPixel.h>
#include "DHT20.h"
#include <HCSR04.h>

#include <TFT_eSPI.h>
#include "gameover.h"
#include "noInternet.h"
#include "imgData.h"
#include "config.h"

// 贪吃蛇结构体定义
struct Snake {
  int x[50];
  int y[50];
  int length;
  int direction;
};

Snake snake;
int foodX, foodY;

// 屏幕分辨率
#define SCREEN_WIDTH 320
#define SCREEN_HEIGHT 240

// 弹珠结构体
struct Marble {
  int x;
  int y;
  int vx;
  int vy;
};

Marble marble;

// 挡板结构体
struct Paddle {
  int x;
  int y;
  int width;
  int height;
};

Paddle paddle;


unsigned long previousTime = 0;
int interval = 0;  // 设置延迟间隔时间，单位毫秒

void delay_new(int wait) {
  interval = wait;
  while (1) {
    unsigned long currentTime = millis();
    if (currentTime - previousTime >= wait) {
      previousTime = currentTime;
      break;
    }
    lv_timer_handler();
  }
}

//RGB
#define LED_PIN 22
#define LED_EN 23
// How many NeoPixels are attached to the Arduino?
#define LED_COUNT 20
#define BRIGHTNESS 10
Adafruit_NeoPixel strip(LED_COUNT, LED_PIN, NEO_RGB + NEO_KHZ800);


//测试标志
uint8_t Count = 0;
char CloseData;
char CloseData1;
int NO_Test_Flag = 0;
int Test_Flag = 0;
int Close_Flag = 0;
int touch_flag = 0;
class LGFX : public lgfx::LGFX_Device {
  lgfx::Panel_ST7789 _panel_instance;
  //    lgfx::Panel_ILI9488     _panel_instance;
  // lgfx::Panel_ILI9341     _panel_instance;
  lgfx::Bus_SPI _bus_instance;  // SPIバスのインスタンス
  lgfx::Touch_FT5x06 _touch_instance;

public:
  LGFX(void) {
    {
      auto cfg = _bus_instance.config();

      // SPIバスの設定
      cfg.spi_host = 0;  // 使用するSPIを選択  ESP32-S2,C3 : SPI2_HOST or SPI3_HOST / ESP32 : VSPI_HOST or HSPI_HOST
      // ※ ESP-IDFバージョンアップに伴い、VSPI_HOST , HSPI_HOSTの記述は非推奨になるため、エラーが出る場合は代わりにSPI2_HOST , SPI3_HOSTを使用してください。
      cfg.spi_mode = 0;           // SPI通信モードを設定 (0 ~ 3)
      cfg.freq_write = 80000000;  // 传输时的SPI时钟（最高80MHz，四舍五入为80MHz除以整数得到的值）
      cfg.freq_read = 16000000;   // 接收时的SPI时钟
      // ※ ESP-IDFバージョンアップに伴い、DMAチャンネルはSPI_DMA_CH_AUTO(自動設定)が推奨になりました。1ch,2chの指定は非推奨になります。
      cfg.pin_sclk = 6;   // SPIのSCLKピン番号を設定
      cfg.pin_mosi = 7;   // SPIのCLKピン番号を設定
      cfg.pin_miso = -1;  // SPIのMISOピン番号を設定 (-1 = disable)
      cfg.pin_dc = 16;    // SPIのD/Cピン番号を設定  (-1 = disable)

      _bus_instance.config(cfg);               // 設定値をバスに反映します。
      _panel_instance.setBus(&_bus_instance);  // バスをパネルにセットします。
    }

    {                                       // 表示パネル制御の設定を行います。
      auto cfg = _panel_instance.config();  // 表示パネル設定用の構造体を取得します。

      cfg.pin_cs = 17;  // CSが接続されているピン番号   (-1 = disable)
      //        cfg.pin_rst = 9;   // RSTが接続されているピン番号  (-1 = disable)
      cfg.pin_rst = -1;   // RSTが接続されているピン番号  (-1 = disable)
      cfg.pin_busy = -1;  // BUSYが接続されているピン番号 (-1 = disable)

      // ※ 以下の設定値はパネル毎に一般的な初期値が設定さ BUSYが接続されているピン番号 (-1 = disable)れていますので、不明な項目はコメントアウトして試してみてください。

      cfg.memory_width = 240;    // ドライバICがサポートしている最大の幅
      cfg.memory_height = 320;   // ドライバICがサポートしている最大の高さ
      cfg.panel_width = 240;     // 実際に表示可能な幅
      cfg.panel_height = 320;    // 実際に表示可能な高さ
      cfg.offset_x = 0;          // パネルのX方向オフセット量
      cfg.offset_y = 0;          // パネルのY方向オフセット量
      cfg.offset_rotation = 1;   //值在旋转方向的偏移0~7（4~7是倒置的）
      cfg.dummy_read_pixel = 8;  // 在读取像素之前读取的虚拟位数
      cfg.dummy_read_bits = 1;   // 读取像素以外的数据之前的虚拟读取位数
      cfg.readable = false;      // 如果可以读取数据，则设置为 true
      cfg.invert = true;         // 如果面板的明暗反转，则设置为 true
      cfg.rgb_order = false;     // 如果面板的红色和蓝色被交换，则设置为 true
      cfg.dlen_16bit = false;    // 对于以 16 位单位发送数据长度的面板，设置为 true
      cfg.bus_shared = false;    // 如果总线与 SD 卡共享，则设置为 true（使用 drawJpgFile 等执行总线控制）

      _panel_instance.config(cfg);
    }

    {  // タッチスクリーン制御の設定を行います。（必要なければ削除）
      auto cfg = _touch_instance.config();

      cfg.x_min = 0;            // タッチスクリーンから得られる最小のX値(生の値)
      cfg.x_max = 239;          // タッチスクリーンから得られる最大のX値(生の値)
      cfg.y_min = 0;            // タッチスクリーンから得られる最小のY値(生の値)
      cfg.y_max = 319;          // タッチスクリーンから得られる最大のY値(生の値)
      cfg.pin_int = 25;         // INTが接続されているピン番号
      cfg.pin_rst = 24;
      cfg.bus_shared = false;   // 如果您使用与屏幕相同的总线，则设置为 true
      cfg.offset_rotation = 0;  // 显示和触摸方向不匹配时的调整 设置为 0 到 7 的值

      // I2C接続の場合
      cfg.i2c_port = 0;     // 使用するI2Cを選択 (0 or 1)
      cfg.i2c_addr = 0x38;  // I2Cデバイスアドレス番号
      cfg.pin_sda = 4;      // SDAが接続されているピン番号
      cfg.pin_scl = 5;      // SCLが接続されているピン番号
      cfg.freq = 400000;    // I2Cクロックを設定

      _touch_instance.config(cfg);
      _panel_instance.setTouch(&_touch_instance);  // タッチスクリーンをパネルにセットします。
    }

    setPanel(&_panel_instance);
  }
};
LGFX gfx;

/*Change to your screen resolution*/
static const uint16_t screenWidth = 320;
static const uint16_t screenHeight = 240;

static lv_disp_draw_buf_t draw_buf;
static lv_color_t buf[screenWidth * screenHeight / 10];
//显示刷新
void my_disp_flush(lv_disp_drv_t *disp, const lv_area_t *area, lv_color_t *color_p) {
  if (gfx.getStartCount() > 0) {
    gfx.endWrite();
  }
  gfx.pushImageDMA(area->x1, area->y1, area->x2 - area->x1 + 1, area->y2 - area->y1 + 1, (lgfx::rgb565_t *)&color_p->full);

  lv_disp_flush_ready(disp);  //告诉lvgl刷新完成
}

uint16_t touchX, touchY;
void my_touchpad_read(lv_indev_drv_t *indev_driver, lv_indev_data_t *data) {
  data->state = LV_INDEV_STATE_REL;
  if (gfx.getTouch(&touchX, &touchY)) {
    data->state = LV_INDEV_STATE_PR;
    //设置坐标(隆显的屏幕Y轴相反，普阳的屏幕X轴相反)screenHeight -
    data->point.x = touchX;
    data->point.y = touchY;  //旋转后Y轴相反了
    Serial.print("Data x ");
    Serial.println(data->point.x);
    Serial.print("Data y ");
    Serial.println(data->point.y);
  }
}


//UI
#include "ui.h"
static int first_flag = 0;
extern int zero_clean;
extern int goto_widget_flag;
extern int bar_flag;
extern lv_obj_t *ui_MENU;
extern lv_obj_t *ui_TOUCH;
extern lv_obj_t *ui_JIAOZHUN;
extern lv_obj_t *ui_Label2;
static lv_obj_t *ui_Label;   //TOUCH界面label
static lv_obj_t *ui_Label3;  //TOUCH界面label3
static lv_obj_t *ui_Labe2;   //Menu界面进度条label
static lv_obj_t *bar;        //Menu界面进度条

static int val = 100;

/*RGB相关函数*/
void colorWipe(uint32_t color, int wait) {
  if (Style_1 == 0)
    return;
  for (int i = 0; i < strip.numPixels(); i++) {  // For each pixel in strip...
    strip.setPixelColor(i, color);               //  Set pixel's color (in RAM)
    strip.show();                                //  Update strip to match
    delay_new(wait);                             //  Pause for a moment
    lv_timer_handler();
  }
}
void colorWipe1(uint32_t color, int wait) {

  for (int i = 0; i < strip.numPixels(); i++) {  // For each pixel in strip...
    strip.setPixelColor(i, color);               //  Set pixel's color (in RAM)
    strip.show();                                //  Update strip to match
    delay(wait);                                 //  Pause for a moment
  }
}
// Input a value 0 to 255 to get a color value.
// The colours are a transition r - g - b - back to r.
uint32_t Wheel(byte WheelPos) {
  WheelPos = 255 - WheelPos;
  if (WheelPos < 85) {
    return strip.Color(255 - WheelPos * 3, 0, WheelPos * 3);
  }
  if (WheelPos < 170) {
    WheelPos -= 85;
    return strip.Color(0, WheelPos * 3, 255 - WheelPos * 3);
  }
  WheelPos -= 170;
  return strip.Color(WheelPos * 3, 255 - WheelPos * 3, 0);
}

// Slightly different, this makes the rainbow equally distributed throughout
void rainbowCycle(uint8_t wait) {
  uint16_t i, j;
  if (Style_4 == 0)
    return;
  for (j = 0; j < 39; j++) {  //256 * 5 5 cycles of all colors on wheel
    for (i = 0; i < strip.numPixels(); i++) {
      strip.setPixelColor(i, Wheel(((i * 256 / strip.numPixels()) + j) & 255));
      lv_timer_handler();
    }
    strip.show();
    strip.setBrightness(j % 40);
    lv_timer_handler();
    delay_new(wait);
    if (Style_4 == 0)
      return;
  }
  for (j = 39; j > 0; j--) {  //256 * 5 5 cycles of all colors on wheel
    for (i = 0; i < strip.numPixels(); i++) {
      strip.setPixelColor(i, Wheel(((i * 256 / strip.numPixels()) + j) & 255));
      lv_timer_handler();
    }
    strip.show();
    strip.setBrightness(j % 40);

    lv_timer_handler();
    delay_new(wait);

    if (Style_4 == 0)
      return;
  }
}
void whiteOverRainbow(int whiteSpeed, int whiteLength) {
  if (Style_2 == 0)
    return;
  if (whiteLength >= strip.numPixels()) whiteLength = strip.numPixels() - 1;

  int head = whiteLength - 1;
  int tail = 0;
  int loops = 3;
  int loopNum = 0;
  uint32_t lastTime = millis();
  uint32_t firstPixelHue = 0;

  for (;;) {                                       // Repeat forever (or until a 'break' or 'return')
    for (int i = 0; i < strip.numPixels(); i++) {  // For each pixel in strip...
      if (((i >= tail) && (i <= head)) ||          //  If between head & tail...
          ((tail > head) && ((i >= tail) || (i <= head)))) {
        strip.setPixelColor(i, strip.Color(0, 0, 0, 255));  // Set white
      } else {                                              // else set rainbow
        int pixelHue = firstPixelHue + (i * 65536L / strip.numPixels());
        strip.setPixelColor(i, strip.gamma32(strip.ColorHSV(pixelHue)));
      }
      if (Style_2 == 0)
        return;
    }

    strip.show();  // Update strip with new contents
    lv_timer_handler();
    // There's no delay here, it just runs full-tilt until the timer and
    // counter combination below runs out.

    firstPixelHue += 40;  // Advance just a little along the color wheel

    if ((millis() - lastTime) > whiteSpeed) {  // Time to update head/tail?
      if (++head >= strip.numPixels()) {       // Advance head, wrap around
        head = 0;
        if (++loopNum >= loops) return;
      }
      if (++tail >= strip.numPixels()) {  // Advance tail, wrap around
        tail = 0;
      }
      lastTime = millis();  // Save time of last movement
    }
  }
}

void pulseWhite(uint8_t wait) {
  for (int j = 0; j < 256; j++) {  // Ramp up from 0 to 255
    // Fill entire strip with white at gamma-corrected brightness level 'j':
    strip.fill(strip.Color(0, 0, 0, strip.gamma8(j)));
    strip.show();
    delay(wait);
    lv_timer_handler();
    if (Style_3 == 0)
      return;
  }

  for (int j = 255; j >= 0; j--) {  // Ramp down from 255 to 0
    strip.fill(strip.Color(0, 0, 0, strip.gamma8(j)));
    strip.show();
    delay(wait);
    lv_timer_handler();
    if (Style_3 == 0)
      return;
  }
}
void theaterChaseRainbow(int wait) {
  int firstPixelHue = 0;           // First pixel starts at red (hue 0)
  for (int a = 0; a < 30; a++) {   // Repeat 30 times...
    for (int b = 0; b < 3; b++) {  //  'b' counts from 0 to 2...
      strip.clear();               //   Set all pixels in RAM to 0 (off)
      // 'c' counts up from 'b' to end of strip in increments of 3...
      for (int c = b; c < strip.numPixels(); c += 3) {
        // hue of pixel 'c' is offset by an amount to make one full
        // revolution of the color wheel (range 65536) along the length
        // of the strip (strip.numPixels() steps):
        int hue = firstPixelHue + c * 65536L / strip.numPixels();
        uint32_t color = strip.gamma32(strip.ColorHSV(hue));  // hue -> RGB
        strip.setPixelColor(c, color);                        // Set pixel 'c' to value 'color'
      }
      strip.show();  // Update strip with new contents
      delay(wait);   // Pause for a moment
      lv_timer_handler();
      if (Style_4 == 0)
        return;
      firstPixelHue += 65536 / 90;  // One cycle of color wheel over 90 frames
    }
  }
}
void theaterChase(uint32_t color, int wait) {
  for (int a = 0; a < 10; a++) {   // Repeat 10 times...
    for (int b = 0; b < 3; b++) {  //  'b' counts from 0 to 2...
      strip.clear();               //   Set all pixels in RAM to 0 (off)
      // 'c' counts up from 'b' to end of strip in steps of 3...
      for (int c = b; c < strip.numPixels(); c += 3) {
        strip.setPixelColor(c, color);  // Set pixel 'c' to value 'color'
      }
      strip.show();  // Update strip with new contents
      delay(wait);   // Pause for a moment
      lv_timer_handler();
      if (Style_4 == 0)
        return;
    }
  }
}
void rainbowFade2White(int wait, int rainbowLoops) {
  if (Style_3 == 0)
    return;

  int fadeVal = 0, fadeMax = 100;

  // Hue of first pixel runs 'rainbowLoops' complete loops through the color
  // wheel. Color wheel has a range of 65536 but it's OK if we roll over, so
  // just count from 0 to rainbowLoops*65536, using steps of 256 so we
  // advance around the wheel at a decent clip.
  for (uint32_t firstPixelHue = 0; firstPixelHue < rainbowLoops * 65536;
       firstPixelHue += 256) {

    for (int i = 0; i < strip.numPixels(); i++) {  // For each pixel in strip...

      // Offset pixel hue by an amount to make one full revolution of the
      // color wheel (range of 65536) along the length of the strip
      // (strip.numPixels() steps):
      uint32_t pixelHue = firstPixelHue + (i * 65536L / strip.numPixels());

      // strip.ColorHSV() can take 1 or 3 arguments: a hue (0 to 65535) or
      // optionally add saturation and value (brightness) (each 0 to 255).
      // Here we're using just the three-argument variant, though the
      // second value (saturation) is a constant 255.
      strip.setPixelColor(i, strip.gamma32(strip.ColorHSV(pixelHue, 255,
                                                          255 * fadeVal / fadeMax)));
    }

    strip.show();
    delay_new(wait);
    lv_timer_handler();

    if (firstPixelHue < 65536) {                                 // First loop,
      if (fadeVal < fadeMax) fadeVal++;                          // fade in
    } else if (firstPixelHue >= ((rainbowLoops - 1) * 65536)) {  // Last loop,
      if (fadeVal > 0) fadeVal--;                                // fade out
    } else {
      fadeVal = fadeMax;  // Interim loop, make sure fade is at max
    }
  }



  delay_new(200);  // Pause 1/2 second
}
//game1-设置
TFT_eSPI tft = TFT_eSPI();
TFT_eSprite img = TFT_eSprite(&tft);
TFT_eSprite img2 = TFT_eSprite(&tft);
TFT_eSprite img3 = TFT_eSprite(&tft);
TFT_eSprite img4 = TFT_eSprite(&tft);

TFT_eSprite e = TFT_eSprite(&tft);
TFT_eSprite e2 = TFT_eSprite(&tft);

String inputString = "";      // a String to hold incoming data
bool stringComplete = false;  // whether the string is complete

int dinoW = 33;
int dinoH = 35;
float linesX[6];
int linesW[6];
float linesX2[6];
int linesW2[6];
float clouds[2] = { (float)random(0, 80), (float)random(100, 180) };
float bumps[2];
int bumpsF[2];
int eW = 18;
int eH = 38;

float eX[2] = { (float)random(240, 310), (float)random(380, 460) };
int ef[2] = { 0, 1 };

float roll_speed = GAME_SPEED;
float cloudSpeed = 0.4;
int x = 30;
int y = 58;
float dir = -1.4;
int frames = 0;
int f = 0;
bool gameRun = 0;
int score = 0;
int score_v = 0;
int last_score = 0;
unsigned long start_t = 0;
int t = 0;
bool button_jump = 0;
bool button_start = 0;


unsigned char key_text = 0;
// 记录起始触摸点
int startX;
int startY;
bool isTouching = false;
const int threshold = 25;
const int clickThreshold = 15;  // 点击判定的距离阈值
bool Interface_flag = false;
bool stop_flag = false;

//game2
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
void loop() {

  lv_timer_handler();
  Scan_button();
  delay(10);
  if (game_1 == 1) {
    gfx.fillScreen(TFT_BLACK);
    digitalWrite(0, LOW);
    game_1_test();
    delay(100);
    //强制刷新，避免黑屏
    digitalWrite(0, HIGH);
    lv_timer_handler();
    lv_obj_invalidate(lv_scr_act());
    lv_obj_clear_state(ui_Switch6, LV_STATE_CHECKED);
  }
  if (game_2 == 1) {
    gfx.fillScreen(TFT_BLACK);
    digitalWrite(0, LOW);
    game_2_test();
    //强制刷新，避免黑屏
    digitalWrite(0, LOW);
    ui_init();
    _ui_screen_change(&ui_Screen2, LV_SCR_LOAD_ANIM_FADE_ON, 500, 0, &ui_Screen2_screen_init);
    lv_timer_handler();
    lv_tabview_set_act(ui_TabView2, 2, LV_ANIM_ON);
    lv_timer_handler();
    lv_obj_invalidate(lv_scr_act());
    // lv_obj_clear_state(ui_Switch7, LV_STATE_CHECKED);
    digitalWrite(0, HIGH);
  }
  if (game_3 == 1) {
    gfx.fillScreen(TFT_BLACK);
    digitalWrite(0, LOW);
    game_3_test();
    //强制刷新，避免黑屏
    digitalWrite(0, LOW);
    ui_init();
    _ui_screen_change(&ui_Screen2, LV_SCR_LOAD_ANIM_FADE_ON, 500, 0, &ui_Screen2_screen_init);
    lv_timer_handler();
    lv_tabview_set_act(ui_TabView2, 2, LV_ANIM_ON);
    lv_timer_handler();
    lv_obj_invalidate(lv_scr_act());
    // lv_obj_clear_state(ui_Switch7, LV_STATE_CHECKED);
    digitalWrite(0, HIGH);
  }
}
bool State_flag = true;
bool Open_menu = false;
bool game2_flag = true;
bool game3_flag = true;

void game_3_test() {
  snake_initialize();
  food_initialize();
  unsigned long lastKeyCheckTime = 0;
  unsigned long lastKeyCheckTime1 = 0;
  const unsigned long keyCheckInterval = 50;
  const unsigned long keyCheckInterval1 = 400;
  game3_flag = true;
  digitalWrite(0, HIGH);
  while (1) {
    unsigned long currentTime = millis();
    if (currentTime - lastKeyCheckTime >= keyCheckInterval) {
      int adcValue = analogRead(27);
      if (adcValue >= 740 && adcValue <= 750) {
        snake.direction = 3;
      } else if (adcValue >= 860 && adcValue <= 870) {
        snake.direction = 1;
      } else if (adcValue >= 800 && adcValue <= 810) {
        snake.direction = 2;
      } else if (adcValue >= 905 && adcValue <= 915) {
        snake.direction = 0;
      }
      lastKeyCheckTime = currentTime;
    }
    uint16_t touchX1, touchY1;

    // 手势判断
    if (gfx.getTouch(&touchX1, &touchY1)) {
      if (!isTouching) {
        startX = touchX1;
        startY = touchY1;
        isTouching = true;
      } else {
        int yDiff = touchY1 - startY;
        int xDiff = touchX1 - startX;
        // 计算移动距离
        int moveDistance = sqrt(xDiff * xDiff + yDiff * yDiff);
        if (moveDistance < clickThreshold) {
          Serial.println("Click ");
          isTouching = false;
          if (touchY1 >= 180 && touchX1 >= 205 && touchX1 <= 285 && Open_menu == true) {
            State_flag = false;
            game_2_Menu();
            lv_timer_handler();
            Serial.println("State_flag ");
            delay(100);
            while (1) {

              if (gfx.getTouch(&touchX1, &touchY1)) {
                delay(10);
                if (touchY1 >= 180 && touchX1 >= 205 && touchX1 <= 285) {
                  State_flag = true;
                  Open_menu = false;
                  break;
                }
              } else if (touchY1 >= 180 && touchX1 < 115 && touchX1 > 45) {
                Serial.println("return ");
                State_flag = true;
                Open_menu = false;
                game3_flag = false;
                break;
              }
            }
          } else if (touchY1 >= 180 && touchX1 < 115 && touchX1 > 45 && Open_menu == true) {
            Serial.println("return ");
            State_flag = true;
            Open_menu = false;
            game3_flag = false;
          }
        } else if (yDiff < -threshold) {
          Serial.println("sliding");
          isTouching = false;
          Open_menu = true;
        }
      }
    } else {
      isTouching = false;
    }
    if (game3_flag == false) {
      game_3 = 0;
      break;
    }
    if (currentTime - lastKeyCheckTime1 >= keyCheckInterval1) {

      lv_obj_clean(lv_scr_act());
      lv_obj_t *img_bg = lv_img_create(lv_scr_act());
      lv_img_set_src(img_bg, &ui_img_crowpi_320x2400_game_02_01_png);
      lv_obj_center(img_bg);

      draw_snake();
      draw_food();

      snake_move();
      eat_food();
      if (collision_detection()) {
        snake_initialize();
        food_initialize();
      }
      if (Open_menu == true) {
        game_2_Menu();
      }

      lv_timer_handler();
      lastKeyCheckTime1 = currentTime;
    }
    if (Open_menu == true) {
      game_2_Menu();
    }

    lv_timer_handler();
  }
}


void game_2_Menu() {
  ui_Image10 = lv_img_create(lv_scr_act());
  lv_img_set_src(ui_Image10, &ui_img_pico_nav_01_png);
  lv_obj_set_width(ui_Image10, LV_SIZE_CONTENT);   /// 1
  lv_obj_set_height(ui_Image10, LV_SIZE_CONTENT);  /// 1
  lv_obj_set_x(ui_Image10, 0);
  lv_obj_set_y(ui_Image10, 95);
  lv_obj_set_align(ui_Image10, LV_ALIGN_CENTER);
  lv_obj_add_flag(ui_Image10, LV_OBJ_FLAG_ADV_HITTEST);   /// Flags
  lv_obj_clear_flag(ui_Image10, LV_OBJ_FLAG_SCROLLABLE);  /// Flags


  ui_btn1 = lv_btn_create(ui_Image10);
  lv_obj_set_width(ui_btn1, 30);
  lv_obj_set_height(ui_btn1, 30);
  lv_obj_set_x(ui_btn1, -85);
  lv_obj_set_y(ui_btn1, 0);
  lv_obj_set_align(ui_btn1, LV_ALIGN_CENTER);
  lv_obj_add_flag(ui_btn1, LV_OBJ_FLAG_SCROLL_ON_FOCUS);  /// Flags
  lv_obj_clear_flag(ui_btn1, LV_OBJ_FLAG_SCROLLABLE);     /// Flags
  // lv_obj_set_style_bg_color(ui_btn1, lv_color_hex(0xFFFFFF), LV_PART_MAIN | LV_STATE_DEFAULT);
  // lv_obj_set_style_bg_opa(ui_btn1, 255, LV_PART_MAIN | LV_STATE_DEFAULT);
  lv_obj_set_style_bg_img_src(ui_btn1, &ui_img_pico_icon_01_png, LV_PART_MAIN | LV_STATE_DEFAULT);
  ui_btn2 = lv_btn_create(ui_Image10);
  lv_obj_set_width(ui_btn2, 30);
  lv_obj_set_height(ui_btn2, 30);
  lv_obj_set_x(ui_btn2, 65);
  lv_obj_set_y(ui_btn2, 0);
  lv_obj_set_align(ui_btn2, LV_ALIGN_CENTER);
  lv_obj_add_flag(ui_btn2, LV_OBJ_FLAG_SCROLL_ON_FOCUS);  /// Flags
  lv_obj_clear_flag(ui_btn2, LV_OBJ_FLAG_SCROLLABLE);     /// Flags
  // lv_obj_set_style_bg_color(ui_btn1, lv_color_hex(0xFFFFFF), LV_PART_MAIN | LV_STATE_DEFAULT);
  // lv_obj_set_style_bg_opa(ui_btn1, 255, LV_PART_MAIN | LV_STATE_DEFAULT);
  if (State_flag == true) {

    lv_obj_set_style_bg_img_src(ui_btn2, &ui_img_pico_icon_02_png, LV_PART_MAIN | LV_STATE_DEFAULT);

  } else {

    lv_obj_set_style_bg_img_src(ui_btn2, &ui_img_pico_icon_03_png, LV_PART_MAIN | LV_STATE_DEFAULT);
  }
}
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

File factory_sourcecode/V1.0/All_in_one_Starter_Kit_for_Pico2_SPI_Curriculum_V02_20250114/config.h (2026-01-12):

#ifndef _CONFIG_H_
#define _CONFIG_H_

#define DEBUG   0



// Game Setting
#define GAME_SPEED          1.0
#define GAME_SPEEDUP_GAP    0.1      
#define GAME_SPEEDUP_SCORE  100



// UART Command / Event
/*
 * ESP32-ATmega328p UART Communication
 * data format: D_T_STRING:
 * D: Tx Side Device, E-ESP32
 *                    A-ATmega328P
 * T: Data Type, C-Command           
 *               E-Event
 * STRING: command name
 *    FORWARD
 *    BACK
 *    LEFT
 *    RIGHT
 */
#define ESP32_CMD_FORWARD   (char *)"E_C_FORWARD\r\n"
#define ESP32_CMD_BACK      (char *)"E_C_BACK\r\n"
#define ESP32_CMD_LEFT      (char *)"E_C_LEFT\r\n"
#define ESP32_CMD_RIGHT     (char *)"E_C_RIGHT\r\n"
#define ESP32_CMD_LSPIN     (char *)"E_C_LSPIN\r\n"
#define ESP32_CMD_RSPIN     (char *)"E_C_RSPIN\r\n"
#define ESP32_CMD_STOP      (char *)"E_C_STOP\r\n"

#define ATM_EVN_BTNA_PRE    (char *)"A_E_BTN_A_PRE\r\n"   // button a pressed event
#define ATM_EVN_BTNA_REL    (char *)"A_E_BTN_A_REL\r\n"   // button a release event
#define ATM_EVN_BTNB_PRE    (char *)"A_E_BTN_B_PRE\r\n"   // button b pressed event
#define ATM_EVN_BTNB_REL    (char *)"A_E_BTN_B_REL\r\n"   // button b release event


typedef void (*func_t) (void);
typedef struct  {
  char    *string;
  int     len;
  func_t  handler;
} CMD_T;

#endif
